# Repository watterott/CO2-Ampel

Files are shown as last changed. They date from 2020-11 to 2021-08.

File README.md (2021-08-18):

# CO2-Ampel
The CO2-Ampel is a traffic light to show the carbon dioxide concentration in a room.

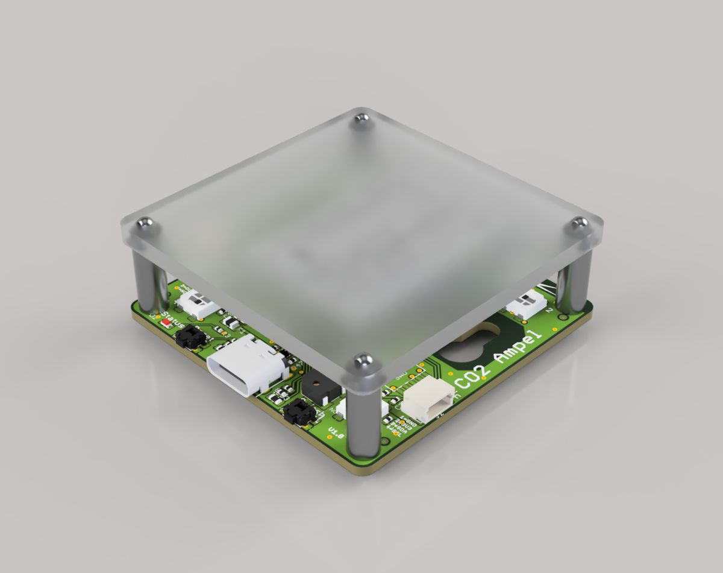
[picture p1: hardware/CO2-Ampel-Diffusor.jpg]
CO2-Ampel


* [Microchip ATSAMD21](https://www.microchip.com/wwwproducts/en/ATSAMD21G18) ARM Cortex-M0+ Microcontroller
* Sensirion [SCD30](https://www.sensirion.com/en/environmental-sensors/carbon-dioxide-sensors/carbon-dioxide-sensors-scd30/) or [SCD40/SCD41](https://www.sensirion.com/en/environmental-sensors/carbon-dioxide-sensors/carbon-dioxide-sensor-scd4x/) CO2 Sensor
* Intelligent WS2812 RGB-LEDs
* Acoustic Buzzer
* Plus Version:
  * [Microchip ATWINC1500B](http://www.microchip.com/wwwproducts/en/ATWINC1500) WiFi/WLAN Network Controller
* Pro Version:
  * Air Pressure Sensor
  * [Microchip ATWINC1500B](http://www.microchip.com/wwwproducts/en/ATWINC1500) WiFi/WLAN Network Controller (optional)
  * [HopeRF RFM95W/RFM96W](https://www.hoperf.com/modules/lora/index.html) LoRa Transceiver (optional)
* USB-C connector for power and data/programming
* USB CDC+MSC Bootloader (Arduino compatible)
* Open-Source and released under the [Creative Commons Attribution Share-Alike License](https://creativecommons.org/licenses/by-sa/4.0/).
* **[Documentation on learn.watterott.com](https://learn.watterott.com/breakouts/co2-ampel/)**

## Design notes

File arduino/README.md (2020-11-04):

# Board Support Package
Board Support Package for [Arduino IDE](https://www.arduino.cc/en/Main/Software).

## Installation

Add the following URL to the Arduino Boards Manager (*File->Preferences*):
```
https://github.com/watterott/CO2-Ampel/raw/master/package_co2ampel_index.json
```
Then open the Arduino Boards Manager (*Tools->Boards->Boards Manager*) and install the 
**Arduino SAMD Boards** and **CO2-Ampel Board**.

## Bootloader

The bootloader can be activated via the Arduino IDE or by doing two reset in 0.5s (double pressing the reset button next to the status LED).

When the bootloader is active then a new program can be loaded via the Arduino IDE and the serial port or via the mass storage device.
For the mass storage device just copy a new binary file (.bin) to the drive.

On Linux/Mac the dd command can be used to write the firmware: ```dd if=APP.BIN of=/media/CO2AMPEL/APP.BIN conv=notrunc```

A binary file can be generated and exported in the Arduino IDE with *Sketch->Export compiled Binary* command.

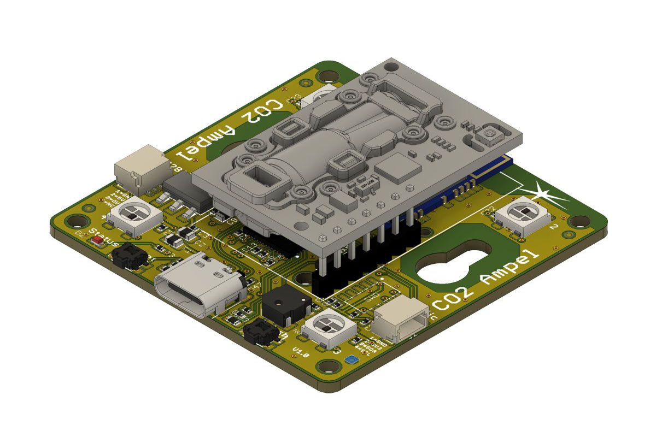
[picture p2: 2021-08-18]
hardware/CO2-Ampel_v10.jpg

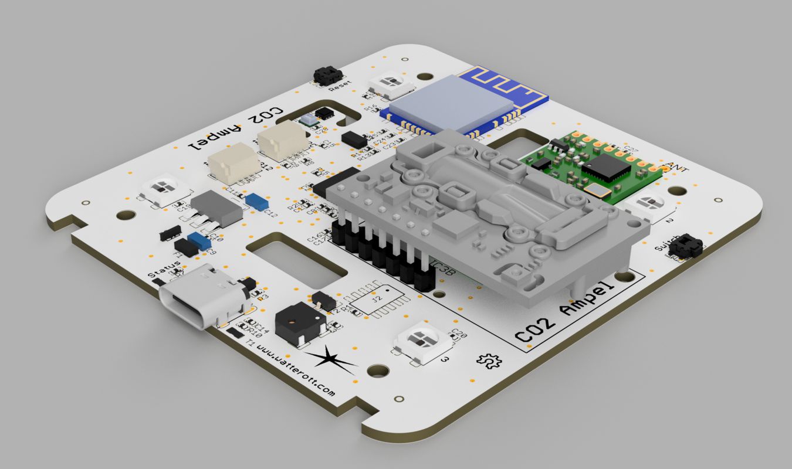
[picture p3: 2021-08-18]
hardware/CO2-Ampel-Pro_v12.jpg

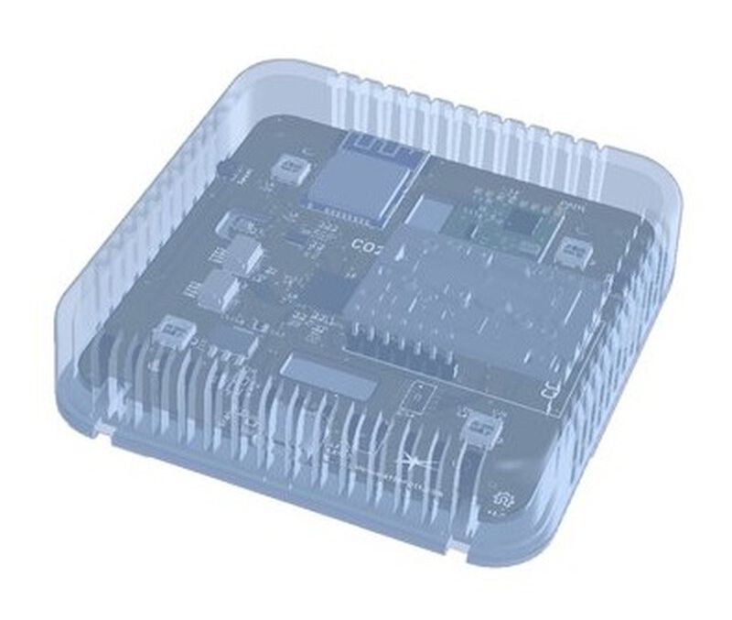
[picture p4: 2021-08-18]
hardware/CO2-Ampel-Pro-Enclosure.jpg

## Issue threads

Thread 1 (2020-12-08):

firmware v7 wrongly calibrated

ernstkl, 2020-12-08:
Hello,

the firmware v7 displays a CO2 ppm value of ca. 220 ppm in a well ventilated office. This is not plausible as fresh air has about 400 ppm CO2.
Doing the check outside, the ppm value drops to zero.

This looks like a wrong calibration to me. According to the readme, doing a calibration usually is not required.

ernstkl, 2020-12-08:
need to check, maybe we miscalibrated ourselves, sorry.

awatterott, 2020-12-08:
Please contact us via mail: support at watterott dot com

Closed 2020-12-08.

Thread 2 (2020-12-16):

Unpopulated component J2 next to Qwiic connector?

reibuehl, 2020-12-16:
I noticed that there is an unpopulated component, J2, next to the Qwiic connector J4 on the v1.1 board. Is there any information about what was supposed to be there?

awatterott, 2020-12-16:
Its a SWD connector for programming/debugging:
https://github.com/watterott/CO2-Ampel/blob/master/hardware/CO2-Ampel_v11.pdf
Please use our support mail address for technical questions.

Closed 2020-12-16.

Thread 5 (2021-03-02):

Firmware co2_covid_v11.bin doesn't seem to work well with v1.1 standard device

olberger, 2021-03-02:
I have tested the co2_covid_v11.bin firmware from
https://learn.watterott.com/breakouts/co2-ampel/getting-started/co2_covid_v11.bin and values reported over the USB serial port (and light colors) seem to be varying to erratically, on my v1.1 standard version.

Firmware co2_covid_v10.bin seems more reliable (smoother evolution of CO2 level).

Maybe this is known : "could cause freezing of standard version on startup (since v5)" seems to indicate a problem with the standard version... or I misunderstand the meaning of that notice : not clear if it applies to the prior versions (bug fixed), or is a known issue with that update... proper changelog/release notes would help (maybe not in the getting started page, but couldn't find more docs...)

Thanks in advance.

awatterott, 2021-03-02:
The different between v10 and v11 is just a fix for the possible freezing, which was caused by the detection code for the plus version.

olberger, 2021-03-02:
OK, so what about the fact that v11 doesn't report values in a sensible way ?

It's no big deal, but may I complain a bit about the quickly closed issues I've just experienced. Please, don't close issues when you responded only to the last sentence, and when the initial part of my issue (and the summary) is the real problem...

It looks like you're worried about issues open... and seems a bit rude for the reporter (who's also a customer FWIW)... I'm just trying to help, and not blaming specifically, but I tend to feel like the issues aren't address somehow.

Or just that's not the place for such discussion... sorry then, but there doesn't seem to be any proper docs about how to report issues anywhere... so... again I don't want to be rude either to you, but it's just a bit confusing without more details on the expected procedures...

Thanks in advance / Vielen Dank.

awatterott, 2021-03-02:
The CO2 values over USB are directly from the SCD30 sensor and the LEDs show an average of those values, which will lead the LEDs to a slower reaction.
Note, with enabled remote mode the measurement interval will be 2s and the default is 3s.
But this is not an issue and if you have technical questions then please contact us via mail.

Closed 2021-03-02.

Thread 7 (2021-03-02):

No values detected on serial link until I flashed the v10+ firmware

olberger, 2021-03-02:
Is there a known issue (undocumented ?) on standard device which could become silent over serial ?

I seem to had proper serial config with cutecom and /dev/ttyACM0 (9600, 8-N1 etc.) but couldn't detect anything on the serial line. Leds were working fine (supposedly, changing to green when getting fresh air, etc.)

After I flashed the v11 firmware, it suddenly started to report sensor values.

Also I couldn't figure out how to detect which version of firmware was running initially as shipped from the store... but that's probably another issue ;-)

awatterott, 2021-03-02:
With v10 the USB detection was changed and previously flow control was used via Arduino Serial functions, which only works directly with the Arduino IDE.
https://github.com/watterott/CO2-Ampel/blob/master/arduino/samd/libraries/CO2-Ampel/examples/CO2-Ampel/CO2-Ampel.ino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
There is currently no command to receive the version of the firmware.

olberger, 2021-03-02:
Uh, sorry but I fail to understand if the above response is supposed to explain why I couldn't see any traffic on the USB serial... Could you explain for someone without knowledge of Arduino stuff ?

awatterott, 2021-03-02:
If the firmware/CO2-Ampel does not detect a USB host device, then no data will be sent via the USB serial port.

Closed 2021-03-02.

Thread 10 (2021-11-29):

checksum in package json missing

sbernhard, 2021-11-29:
**Describe the bug**
The installation of the following command fails because of checksum error.

```arduino-cli core install co2ampel:samd```

Error:
```
Error during install: Cannot install platform: installing platform co2ampel:samd@1.0.7: testing local archive integrity: testing archive checksum: missing checksum for: co2ampel-samd-1.0.7.zip
```

**Expected behavior**
The installation of the co2ampel:samd is successful

**Additional context**
The file https://github.com/watterott/CO2-Ampel/blob/master/package_co2ampel_index.json is missing the checksum like in https://boardsmanager.com/package_move38.com-blinks_index.json

Closed 2022-04-22.

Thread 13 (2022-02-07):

Wifi connection crashes after 1 1/2 day running

HaeckslerSXS, 2022-02-07:
We bought this sensor to messure CO2 in our office, unfortunately the Wifi connection crashes frequently.
We think it would help I we would have the possibility to enter a fix IP.

awatterott, 2022-02-07:
Can you please contact us by email to troubleshoot the problem/issue at first:
https://shop.watterott.com/Contact
We have seen a similar behavior with Ubiquiti devices with an old firmware.

Closed 2022-04-22.

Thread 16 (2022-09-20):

WPA2 Enterprise

realjago, 2022-09-20:
[Feature Request]

hallo, wir verwenden einige CO2-Ampeln und funktioniert sehr gut.
Wir möchten diese auch im Hochschulkontext einsetzen. Lufthygiene in Hörsälen zB.
Dort gibt es aber kein klassisches WPA2, sondern nur WPA2 Enterprise (eduroam), also mit zusätzlichem Benutzer und Passwort zur Verbindung mit dem WLAN.

Es wäre fantastisch, wenn diese Funktionalität noch eingebaut werden könnte.
Das würde auch dafür sorgen, dass noch mehr dieser Geräte bei Ihnen eingekauft werden.

awatterott, 2022-09-21:
Dies ist prinzipiell möglich. Allerdings fehlt in der Arduino WiFi101 Bibliothek aktuell die Unterstützung dafür und eine Umsetzung wäre dadurch sehr aufwendig.
https://github.com/arduino-libraries/WiFi101/issues/199

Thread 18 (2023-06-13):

Hysterese?

mschlenker, 2023-06-13:
In unserem Unternehmen nutzen wir einige CO2-Ampeln für die Überwachung der Luftqualität (wofür sonst...). Leider haben wir festgestellt, dass das Lüftungsverhalten gerade so ist, dass die Schotten wieder dicht gemacht werden, wenn die Ampel gerade so wieder grün ist (oder die Email mit "WARN -> OK" kommt). Für das Checkmk-Plugin bin ich daher dabei, einen Hysteresefaktor als festen Prozentsatz einstellbar zu machen.

D.h., wenn der Übergang OK -> WARN bei Überschreiten von 1000ppm stattfindet und ein Hysteresefaktor von 10% eingestellt ist, findet der Übergang von WARN -> OK erst statt, wenn 900ppm unterschritten werden.

Wenn Ihr daran interessiert seid, den Code für die Hysterese zu übernehmen, werde ich den Code entsprechend sauber strukturieren und gut kommentieren und dann als Pull-Request einreichen. Wäre das in Eurem Interesse?

Liebe Grüße
Mattias

awatterott, 2023-06-13:
Zur Orientierung für das Ende einer Lüftung dient der blaue Bereich (<600ppm).

mschlenker, 2023-06-13:
Hallo Andreas,

Das ist der Idealfall und letztendlich eine Interpretation einer extremen Hysterese. In vielen Umgebungen bedeutet das sehr lange Lüftungszeiten. ASR 3.6 ist zwischen 1000ppm und 2000ppm auch recht flexibel. Ich teste unsere Hysterese nächste Woche mal auf der Checkmk Konferenz und gebe dann nochmal Feedback.

Schönen Abend!
Mattias

Closed 2023-06-24.

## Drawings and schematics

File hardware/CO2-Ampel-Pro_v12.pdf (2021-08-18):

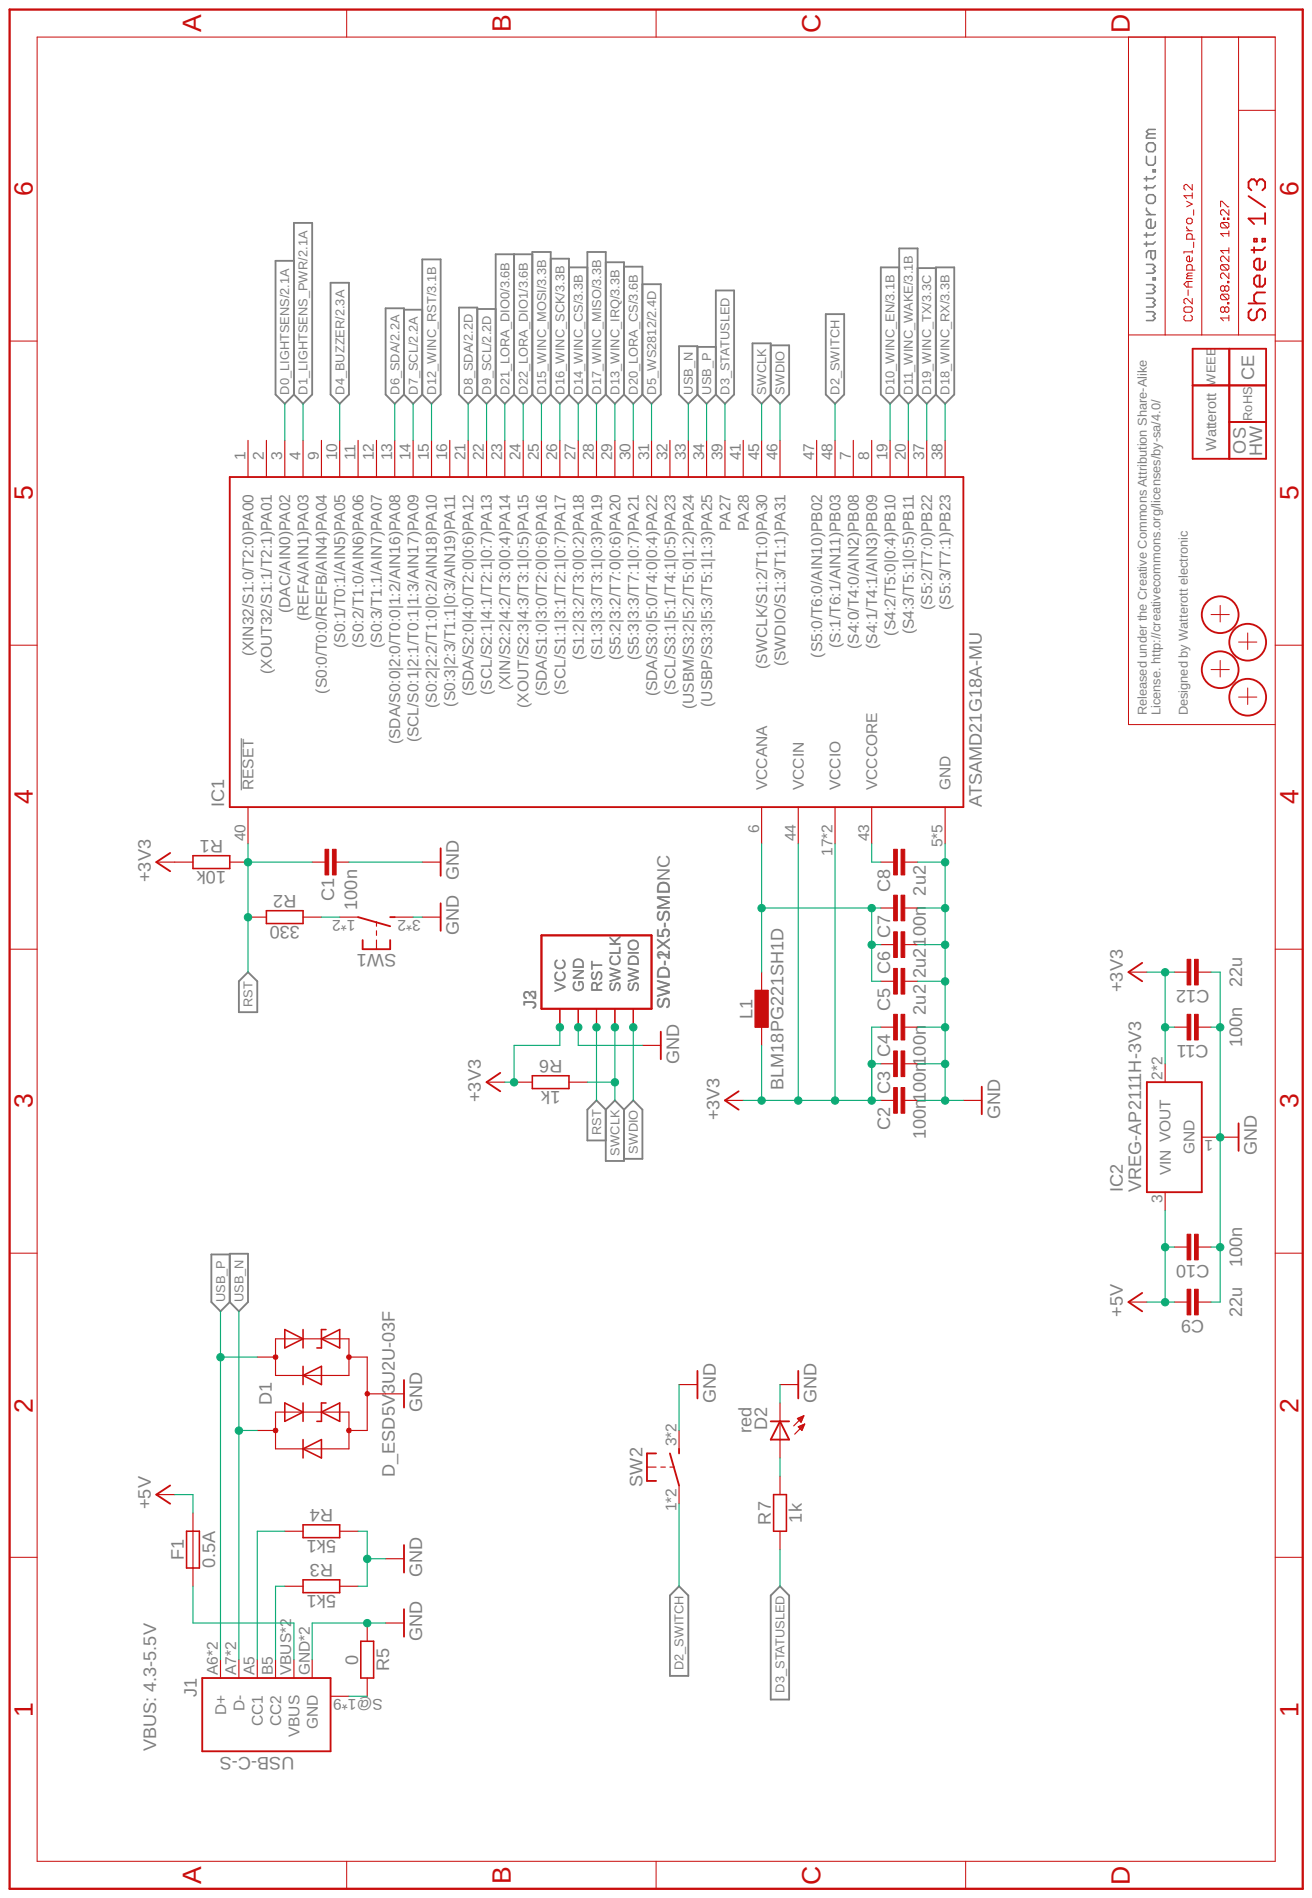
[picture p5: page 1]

VBUS: 4.3-5.5V ATSAMD21G18A-MU +3V3 GND +3V3 GND 0 0.5A +5VD_ESD5V3U2U-03F GND VREG-AP2111H-3V3 +5V GND 100n 100n red 1k 2u2 100n 2u2 100n GND GND k01 033 +3V3 k1 100n 100n 100n 22u 22u GND +3V3 GND BLM18PG221SH1D 2u2 GND 1k5 1k5 GND Released under the Creative Commons Attribution Share-Alike License. http:/ creativecommons.org/licenses/by-sa/4.0/ Designed by Watterott electronic OS HW RESET 40 GND 5*5 VCCANA 6 (XIN32/S1:0/T2:0)PA00 1 (XOUT32/S1:1/T2:1)PA01 2 (DAC/AIN0)PA02 3 (REFA/AIN1)PA03 4 (S0:0/T0:0/REFB/AIN4)PA04 9 (S0:1/T0:1/AIN5)PA05 10 (S0:2/T1:0/AIN6)PA06 11 (S0:3/T1:1/AIN7)PA07 12 (SDA/S0:0|2:0/T0:0|1:2/AIN16)PA08 13 (SCL/S0:1|2:1/T0:1|1:3/AIN17)PA09 14 (S0:2|2:2/T1:0|0:2/AIN18)PA10 15 (S0:3|2:3/T1:1|0:3/AIN19)PA11 16 (SDA/S2:0|4:0/T2:0|0:6)PA12 21 (SCL/S2:1|4:1/T2:1|0:7)PA13 22 (XIN/S2:2|4:2/T3:0|0:4)PA14 23 (XOUT/S2:3|4:3/T3:1|0:5)PA15 24 (SDA/S1:0|3:0/T2:0|0:6)PA16 25 (SCL/S1:1|3:1/T2:1|0:7)PA17 26 (S1:2|3:2/T3:0|0:2)PA18 27 (S1:3|3:3/T3:1|0:3)PA19 28 (S5:2|3:2/T7:0|0:6)PA20 29 (S5:3|3:3/T7:1|0:7)PA21 30 (SDA/S3:0|5:0/T4:0|0:4)PA22 31 (SCL/S3:1|5:1/T4:1|0:5)PA23 32 (USBM/S3:2|5:2/T5:0|1:2)PA24 33 (USBP/S3:3|5:3/T5:1|1:3)PA25 34 PA27 39 PA28 41 (SWCLK/S1:2/T1:0)PA30 45 (SWDIO/S1:3/T1:1)PA31 46 (S5:0/T6:0/AIN10)PB02 47 (S:1/T6:1/AIN11)PB03 48 (S4:0/T4:0/AIN2)PB08 7 (S4:1/T4:1/AIN3)PB09 8 (S4:2/T5:0|0:4)PB10 19 (S4:3/T5:1|0:5)PB11 20 (S5:2/T7:0)PB22 37 (S5:3/T7:1)PB23 38 VCCIO 17*2 VCCIN 44 VCCCORE 43 IC1 2* 1 2* 3 1 WS SWCLK SWDIO VCC GND RST J2SWD-2X5-SMD R5 F1 D1 GND VIN 3 V1 OUT 2*2 IC2 01 C 11 C D2 R7 C8 C7 C5 C1 1 R 2 R 6 R C4 C3 C2 9 C 21 C 1*2 3*2 SW2 L1 C6 CE RoHSWEEE Watterott D+ A6*2 D- A7*2 VBUS VBUS*2 GND GND*2 9* 1 @S CC1 A5 CC2 B5 J1 S- C- BSU 3 R4 R SWCLK SWDIO VCC GND RST J3SWD-1X5-SMDNC D15_WINC_MOSI/3.3B D16_WINC_SCK/3.3B D6_SDA/2.2A D7_SCL/2.2A SWCLK SWCLK SWDIO SWDIO RST RST D17_WINC_MISO/3.3B USB_N USB_N USB_P USB_P D11_WINC_WAKE/3.1B D14_WINC_CS/3.3B D18_WINC_RX/3.3B D19_WINC_TX/3.3C D13_WINC_IRQ/3.3B D8_SDA/2.2D D9_SCL/2.2D D5_WS2812/2.4D D10_WINC_EN/3.1B D4_BUZZER/2.3A D2_SWITCH D2_SWITCH D12_WINC_RST/3.1B D1_LIGHTSENS_PWR/2.1A D0_LIGHTSENS/2.1A D3_STATUSLED D3_STATUSLED D22_LORA_DIO1/3.6B D21_LORA_DIO0/3.6B D20_LORA_CS/3.6B ABCD 1 2 3 4 5 6 ABCD 1 2 3 4 5 6

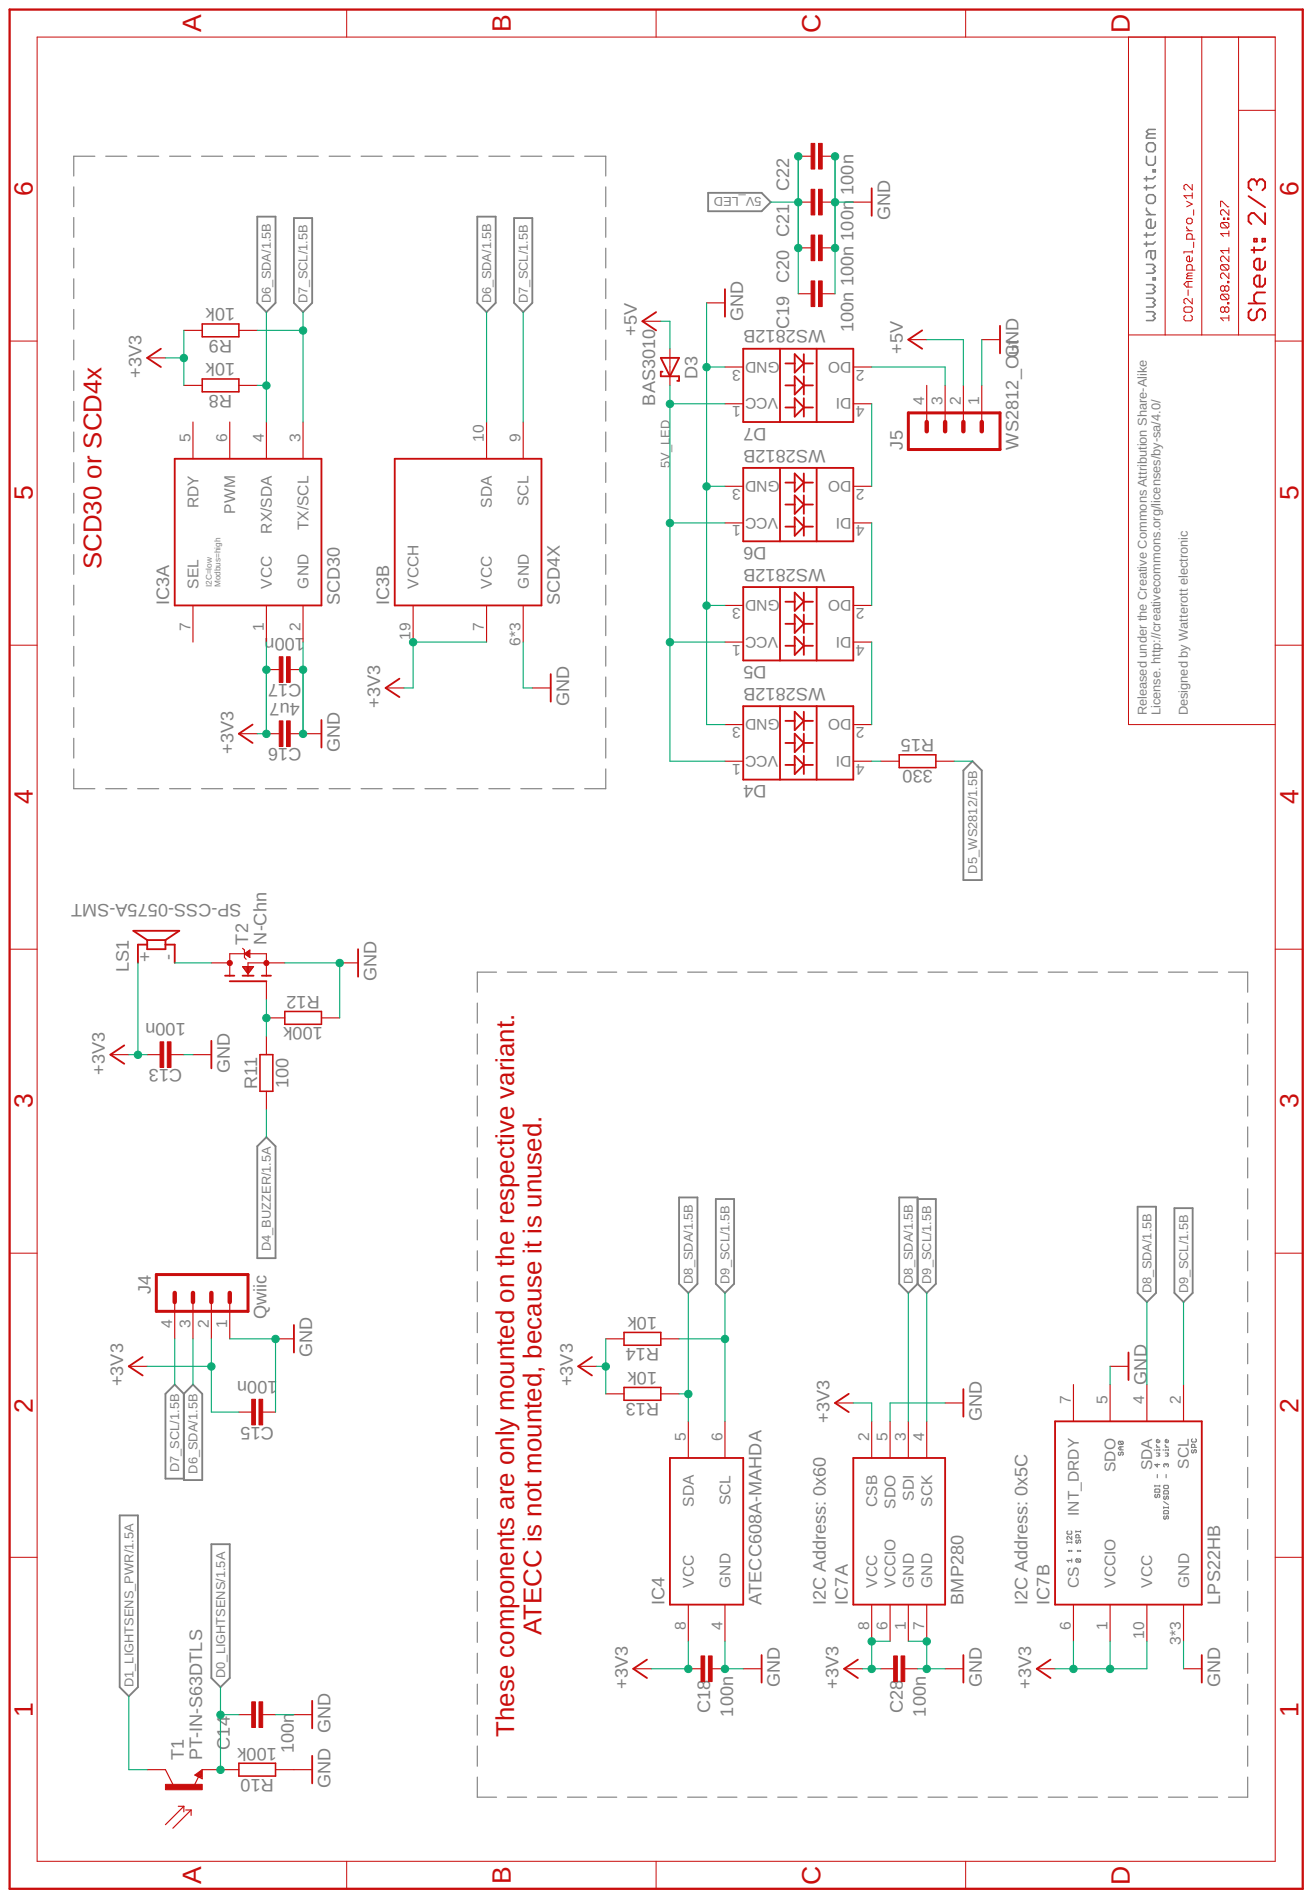
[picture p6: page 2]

I2C Address: 0x60 I2C Address: 0x5C B2182S W B2182S W B2182S W B2182S W SCD30 GND 033 +3V3 GND 100n 100n 100n GND k001 GND Qwiic GND +3V3 N-Chn +3V3 GND k001 100 +3V3 100nGND WS2812_Out GND +5V 100nGND n001 7u4 100n n001 n001 GND k01 k01 +3V3 k01 k01 +3V3 BAS301 +0 5V T MS- A5750- SSC- PS PT-IN-S63DTLS BMP280 100+n3V3 GND +3V3 GND SCD4X +3V3 GND LPS22HB GND +3V3 GND Released under the Creative Commons Attribution Share-Alike License. http:/ creativecommons.org/licenses/by-sa/4.0/ Designed by Watterott electronic 42 13 CCV DNG ODI D 7 D 42 13 CCV DNG ODI D 6 D 42 13 CCV DNG ODI D 5 D 42 13 CCV DNG ODI D 4 D TX/SCL 3 VCC 1 RX/SDA 4 GND 2 PWM 6 RDY 5 SEL 7 I2C=low Modbus=high IC3A 51 R C20 C21 C22 01 R 4321 J4 T2 21 R R11 C18 SCL 6 SDA 5 VCC 8 GND 4 IC4 ATECC608A-MAHDA 4321 J5 C14 71 C 61 C C19 51 C 31 C 31 R 41 R 8 R9 R D3 +- LS1 T1 GND 1 CSB 2 SDI 3 SCK 4 SDO 5 VCCIO 6 GND 7 VCC 8 IC7A C28 SCL 9 VCC 7 SDA 10 GND 6*3 VCCH 19 IC3B SCL 2 VCC 10 SDA 4 GND 3*3 CS 6 SDO 5 INT_DRDY 7 VCCIO 1 IC7B D5_WS2812/1.5B D6_SDA/1.5B D6_SDA/1.5B D6_SDA/1.5B D7_SCL/1.5B D7_SCL/1.5B D7_SCL/1.5B D0_LIGHTSENS/1.5A D4_BUZZER/1.5A D8_SDA/1.5B D8_SDA/1.5B D8_SDA/1.5B D9_SCL/1.5B D9_SCL/1.5B D9_SCL/1.5B D1_LIGHTSENS_PWR/1.5A 5V_LED DEL_V5 These components are only mounted on the respective variant. ATECC is not mounted, because it is unused. SCD30 or SCD4x ABCD 1 2 3 4 5 6 ABCD 1 2 3 4 5 6

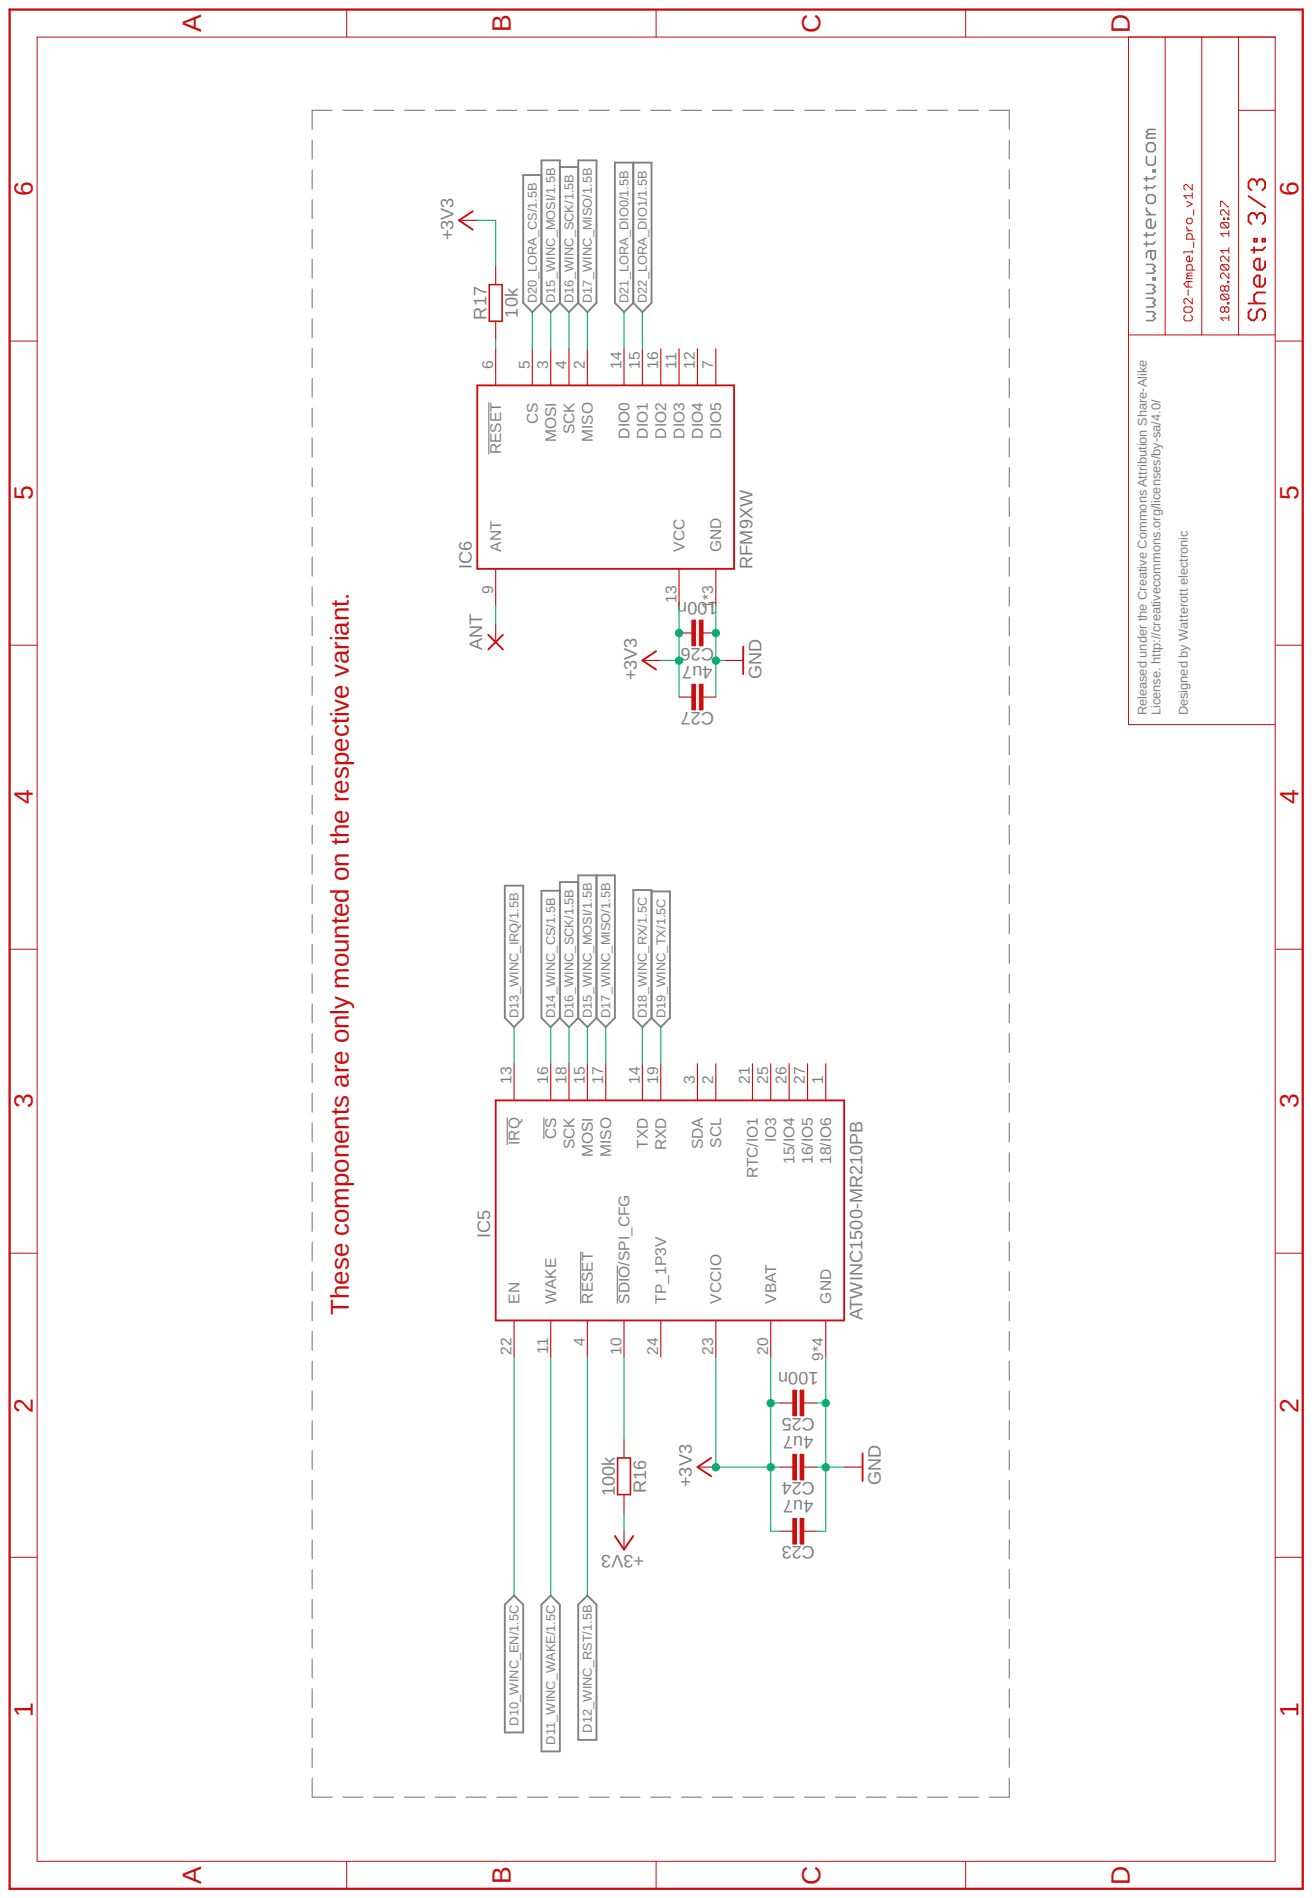
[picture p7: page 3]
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

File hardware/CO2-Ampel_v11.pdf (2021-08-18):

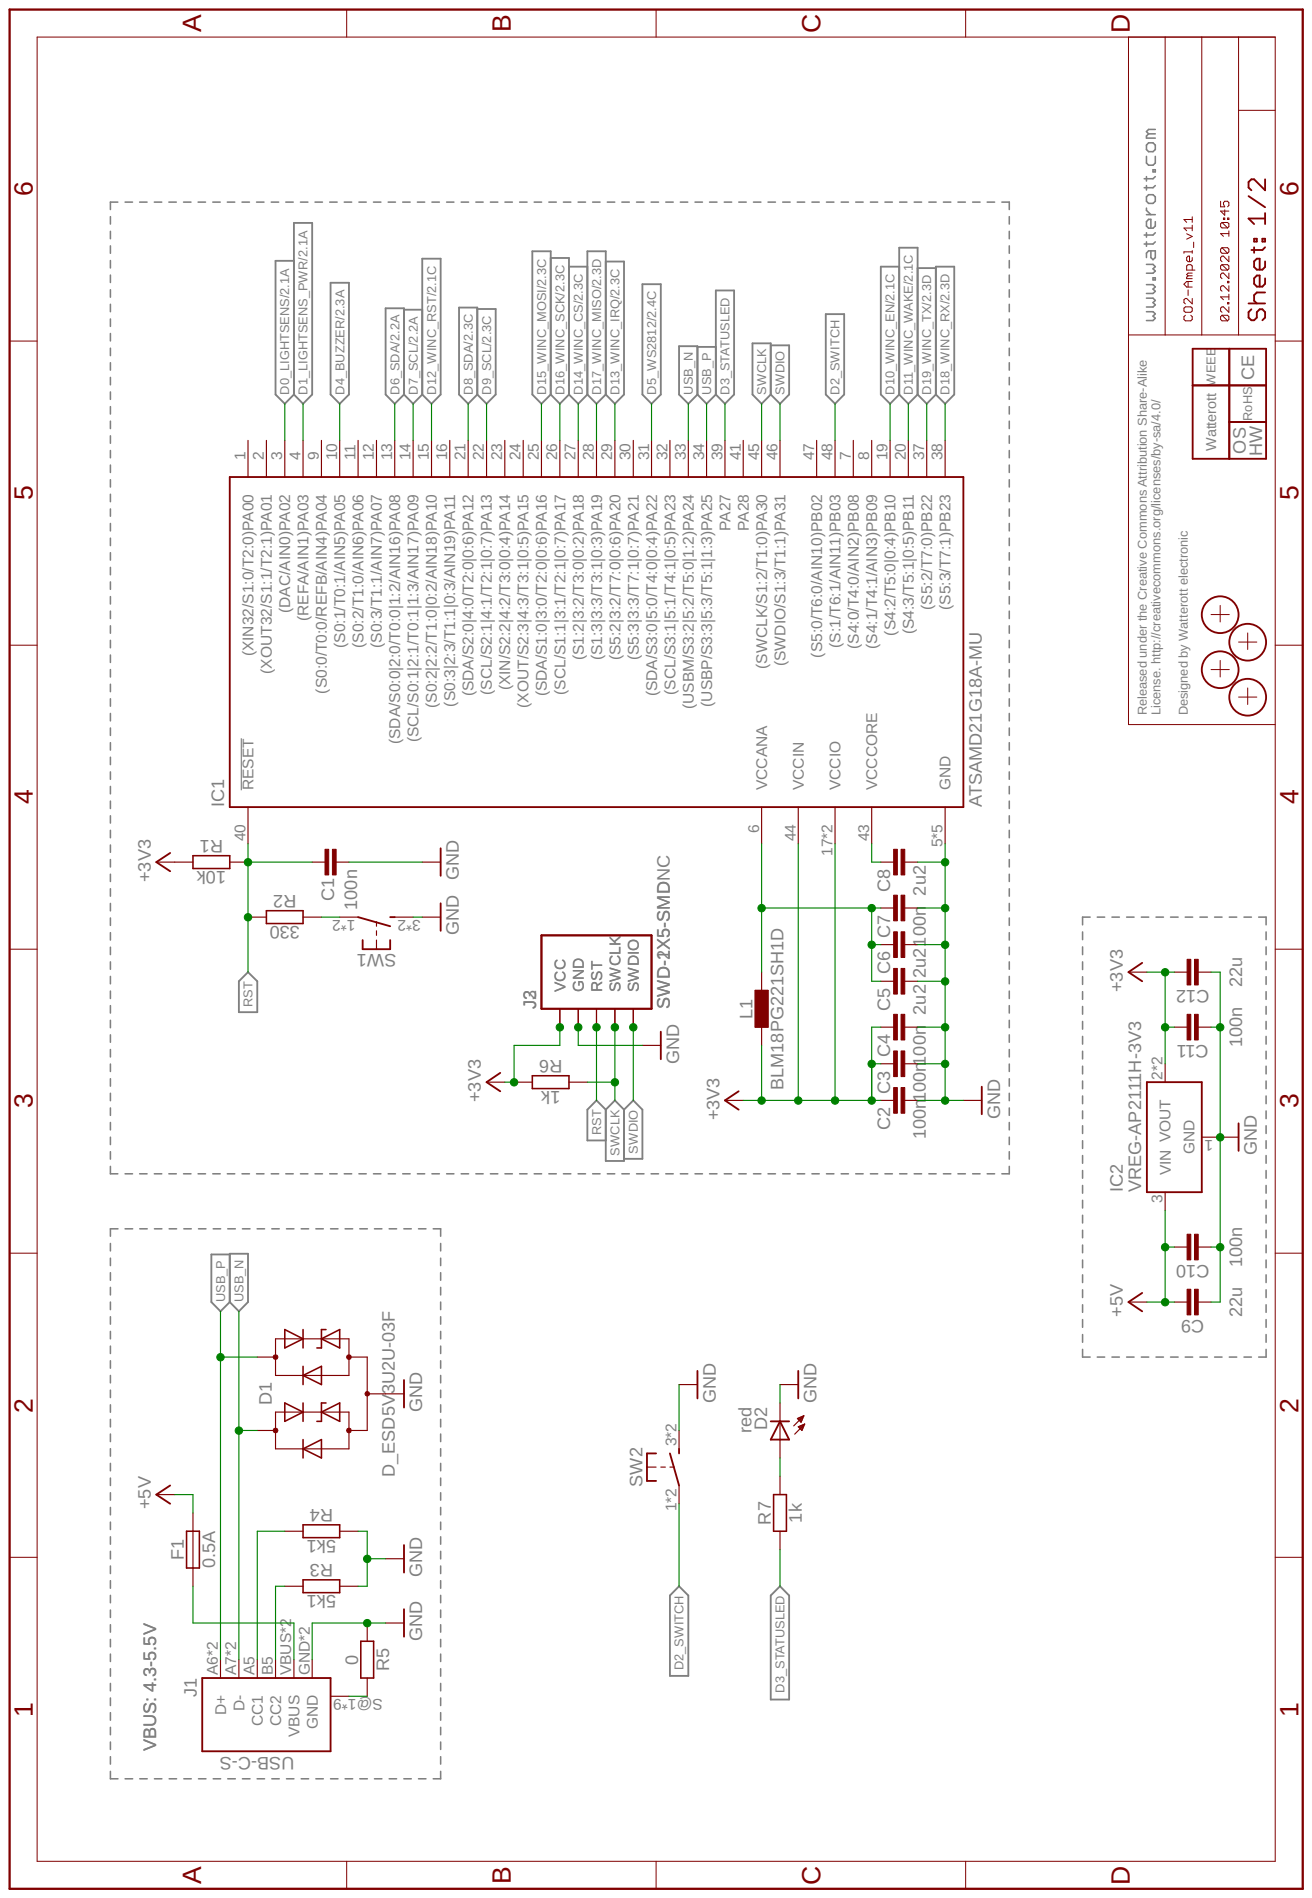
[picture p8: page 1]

VBUS: 4.3-5.5V VBUS: 4.3-5.5V ATSAMD21G18A-MU +3V3 GND +3V3 GND 0 0.5A +5VD_ESD5V3U2U-03F GND VREG-AP2111H-3V3 +5V GND 100n 100n red 1k 2u2 100n 2u2 100n GND GND k01 033 +3V3 k1 100n 100n 100n 22u 22u GND +3V3 GND BLM18PG221SH1D 2u2 GND 1k5 1k5 GND Released under the Creative Commons Attribution Share-Alike License. http:/ creativecommons.org/licenses/by-sa/4.0/ Designed by Watterott electronic OS HW RESET 40 GND 5*5 VCCANA 6 (XIN32/S1:0/T2:0)PA00 1 (XOUT32/S1:1/T2:1)PA01 2 (DAC/AIN0)PA02 3 (REFA/AIN1)PA03 4 (S0:0/T0:0/REFB/AIN4)PA04 9 (S0:1/T0:1/AIN5)PA05 10 (S0:2/T1:0/AIN6)PA06 11 (S0:3/T1:1/AIN7)PA07 12 (SDA/S0:0|2:0/T0:0|1:2/AIN16)PA08 13 (SCL/S0:1|2:1/T0:1|1:3/AIN17)PA09 14 (S0:2|2:2/T1:0|0:2/AIN18)PA10 15 (S0:3|2:3/T1:1|0:3/AIN19)PA11 16 (SDA/S2:0|4:0/T2:0|0:6)PA12 21 (SCL/S2:1|4:1/T2:1|0:7)PA13 22 (XIN/S2:2|4:2/T3:0|0:4)PA14 23 (XOUT/S2:3|4:3/T3:1|0:5)PA15 24 (SDA/S1:0|3:0/T2:0|0:6)PA16 25 (SCL/S1:1|3:1/T2:1|0:7)PA17 26 (S1:2|3:2/T3:0|0:2)PA18 27 (S1:3|3:3/T3:1|0:3)PA19 28 (S5:2|3:2/T7:0|0:6)PA20 29 (S5:3|3:3/T7:1|0:7)PA21 30 (SDA/S3:0|5:0/T4:0|0:4)PA22 31 (SCL/S3:1|5:1/T4:1|0:5)PA23 32 (USBM/S3:2|5:2/T5:0|1:2)PA24 33 (USBP/S3:3|5:3/T5:1|1:3)PA25 34 PA27 39 PA28 41 (SWCLK/S1:2/T1:0)PA30 45 (SWDIO/S1:3/T1:1)PA31 46 (S5:0/T6:0/AIN10)PB02 47 (S:1/T6:1/AIN11)PB03 48 (S4:0/T4:0/AIN2)PB08 7 (S4:1/T4:1/AIN3)PB09 8 (S4:2/T5:0|0:4)PB10 19 (S4:3/T5:1|0:5)PB11 20 (S5:2/T7:0)PB22 37 (S5:3/T7:1)PB23 38 VCCIO 17*2 VCCIN 44 VCCCORE 43 IC1 2* 1 2* 3 1 WS SWCLK SWDIO VCC GND RST J2SWD-2X5-SMD R5 F1 D1 GND VIN 3 V1 OUT 2*2 IC2 01 C 11 C D2 R7 C8 C7 C5 C1 1 R 2 R 6 R C4 C3 C2 9 C 21 C 1*2 3*2 SW2 L1 C6 CE RoHSWEEE Watterott D+ A6*2 D- A7*2 VBUS VBUS*2 GND GND*2 9* 1 @S CC1 A5 CC2 B5 J1 S- C- BSU 3 R4 R SWCLK SWDIO VCC GND RST J3SWD-1X5-SMDNC D15_WINC_MOSI/2.3C D16_WINC_SCK/2.3C D6_SDA/2.2A D7_SCL/2.2A SWCLK SWCLK SWDIO SWDIO RST RST D17_WINC_MISO/2.3D USB_N USB_N USB_P USB_P D11_WINC_WAKE/2.1C D14_WINC_CS/2.3C D18_WINC_RX/2.3D D19_WINC_TX/2.3D D13_WINC_IRQ/2.3C D8_SDA/2.3C D9_SCL/2.3C D5_WS2812/2.4C D10_WINC_EN/2.1C D4_BUZZER/2.3A D2_SWITCH D2_SWITCH D12_WINC_RST/2.1C D1_LIGHTSENS_PWR/2.1A D0_LIGHTSENS/2.1A D3_STATUSLED D3_STATUSLED ABCD 1 2 3 4 5 6 ABCD 1 2 3 4 5 6

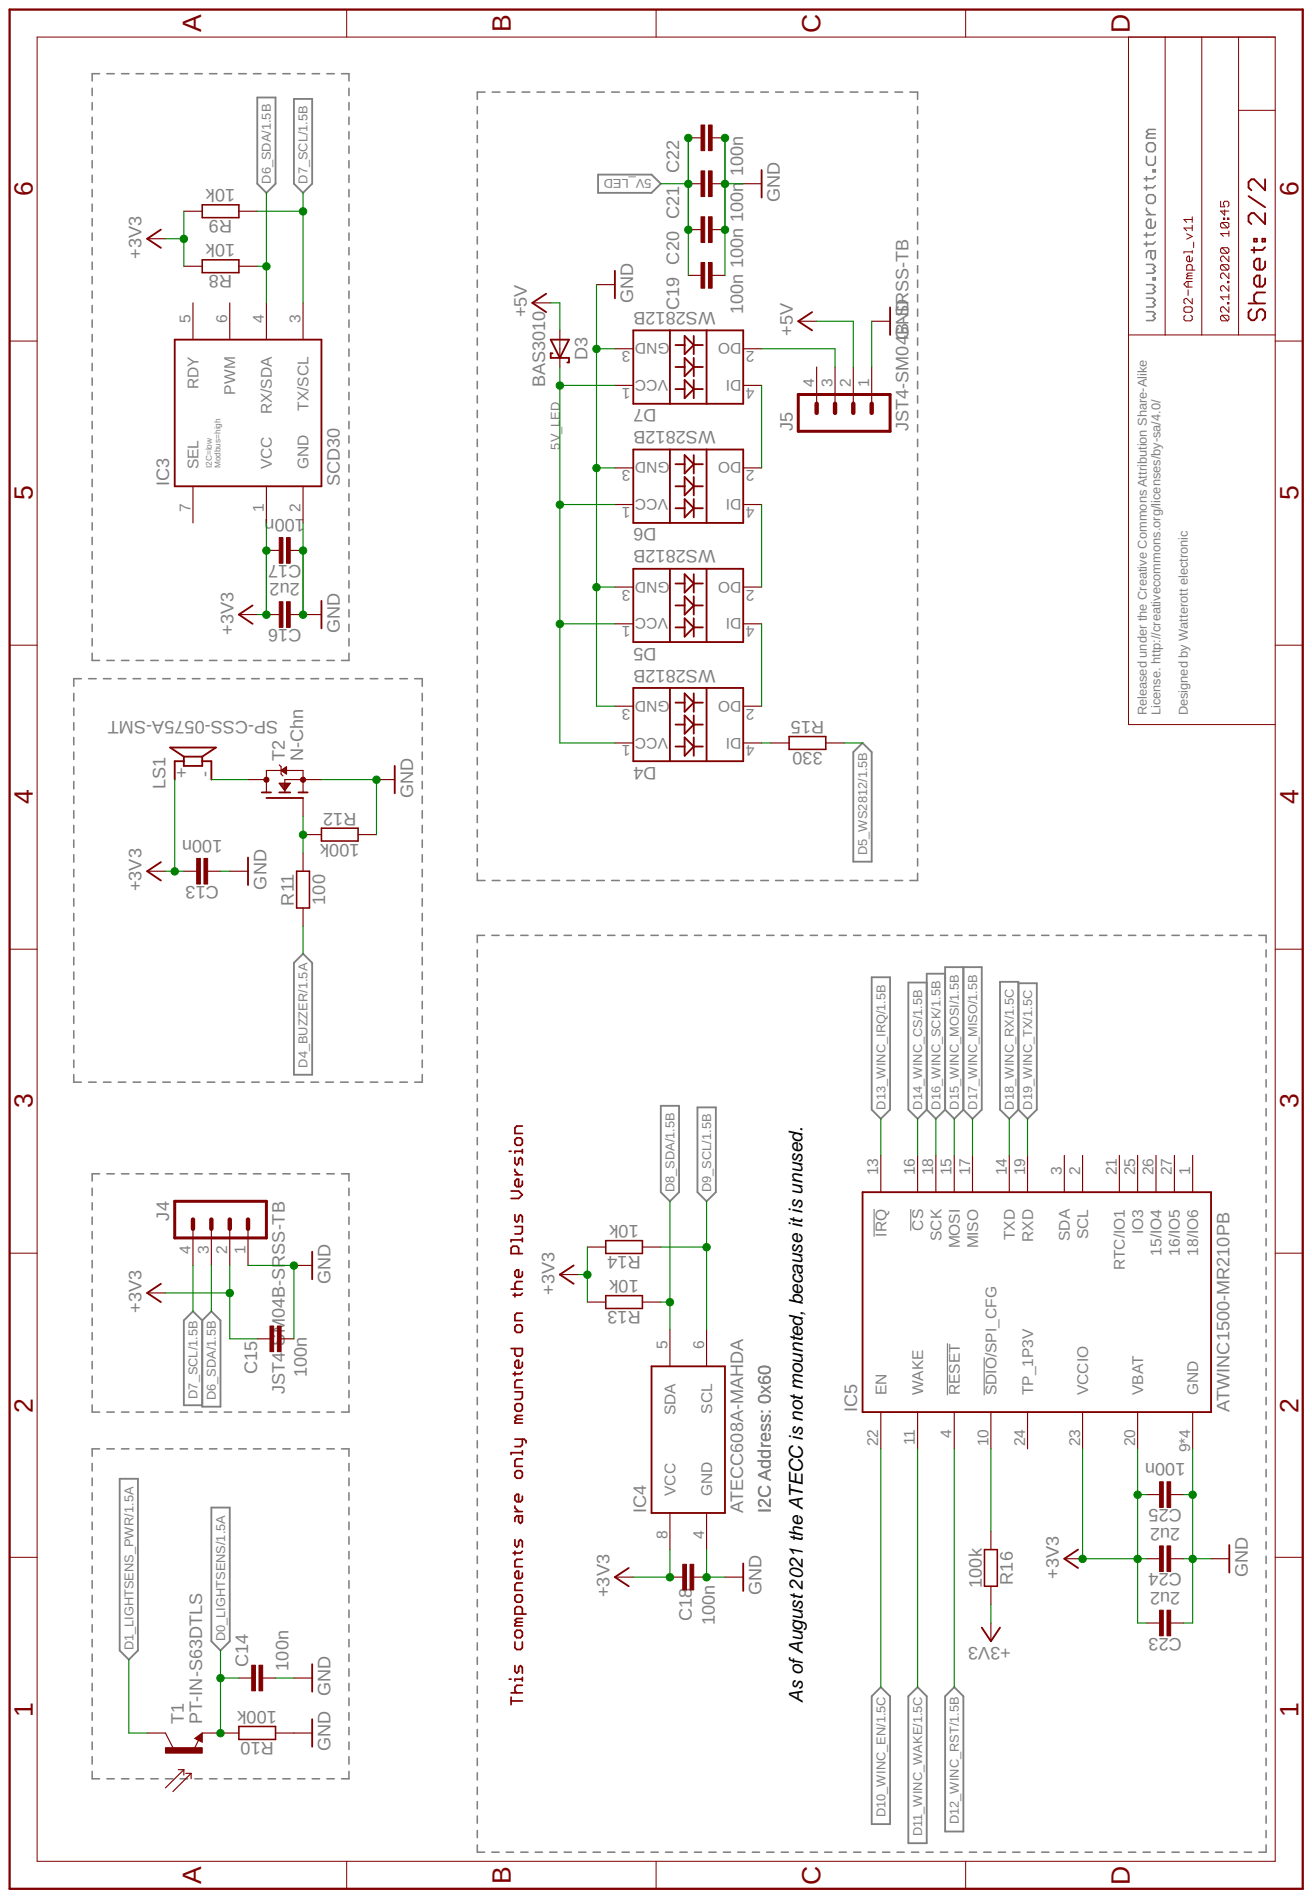
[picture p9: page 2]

I2C Address: 0x60 I2C Address: 0x60 n001 +3V3 GND 3V3+ 100k ATWINC1500-MR210PB 2u2 B2182S W B2182S W B2182S W B2182S W SCD30 GND 033 +3V3 GND 100n 100n 100n GND k001 GND JST4-SM04B-SRSS-TB GND +3V3 N-Chn +3V3 GND k001 100 +3V3 100nGND JST4-SM04B-SRSS-TB GND +5V 100n GND 2u2 n001 2u2 100n 100n n001 GND k01 k01 +3V3 k01 k01 +3V3 BAS301 +0 5V T MS- A5750- SSC- PS PT-IN-S63DTLS Released under the Creative Commons Attribution Share-Alike License. http:/ creativecommons.org/licenses/by-sa/4.0/ Designed by Watterott electronic 52 C R16 16/IO5 27 SCL 2 SDA 3 RESET 4 GND 9*4 SDIO/SPI_CFG 10 WAKE 11 IRQ 13 TXD 14 MOSI 15 CS 16 MISO 17 SCK 18 RXD 19 VBAT 20 RTC/IO1 21 EN 22 VCCIO 23 18/IO6 1 IO3 25 15/IO4 26 TP_1P3V 24 IC5 42 C 42 13 CCV DNG ODI D 7 D 42 13 CCV DNG ODI D 6 D 42 13 CCV DNG ODI D 5 D 42 13 CCV DNG ODI D 4 D TX/SCL 3 VCC 1 RX/SDA 4 GND 2 PWM 6 RDY 5 SEL 7 I2C=low Modbus=high IC3 51 R C20 C21 C22 01 R 4321 J4 T2 21 R R11 C18 SCL 6 SDA 5 VCC 8 GND 4 IC4 ATECC608A-MAHDA 4321 J5 C1432 C 71 C 61 C C19 C15 31 C 31 R 41 R 8 R9 R D3 +- LS1 T1 D15_WINC_MOSI/1.5B D16_WINC_SCK/1.5B D17_WINC_MISO/1.5B D18_WINC_RX/1.5C D10_WINC_EN/1.5C D11_WINC_WAKE/1.5C D5_WS2812/1.5B D12_WINC_RST/1.5B D6_SDA/1.5B D6_SDA/1.5B D7_SCL/1.5B D7_SCL/1.5B D0_LIGHTSENS/1.5A D4_BUZZER/1.5A D8_SDA/1.5B D9_SCL/1.5B D14_WINC_CS/1.5B D19_WINC_TX/1.5C D1_LIGHTSENS_PWR/1.5A D13_WINC_IRQ/1.5B 5V_LED DEL_V5 ABCD 1 2 3 4 5 6 ABCD 1 2 3 4 5 6 As of August 2021 the ATECC is not mounted, because it is unused.

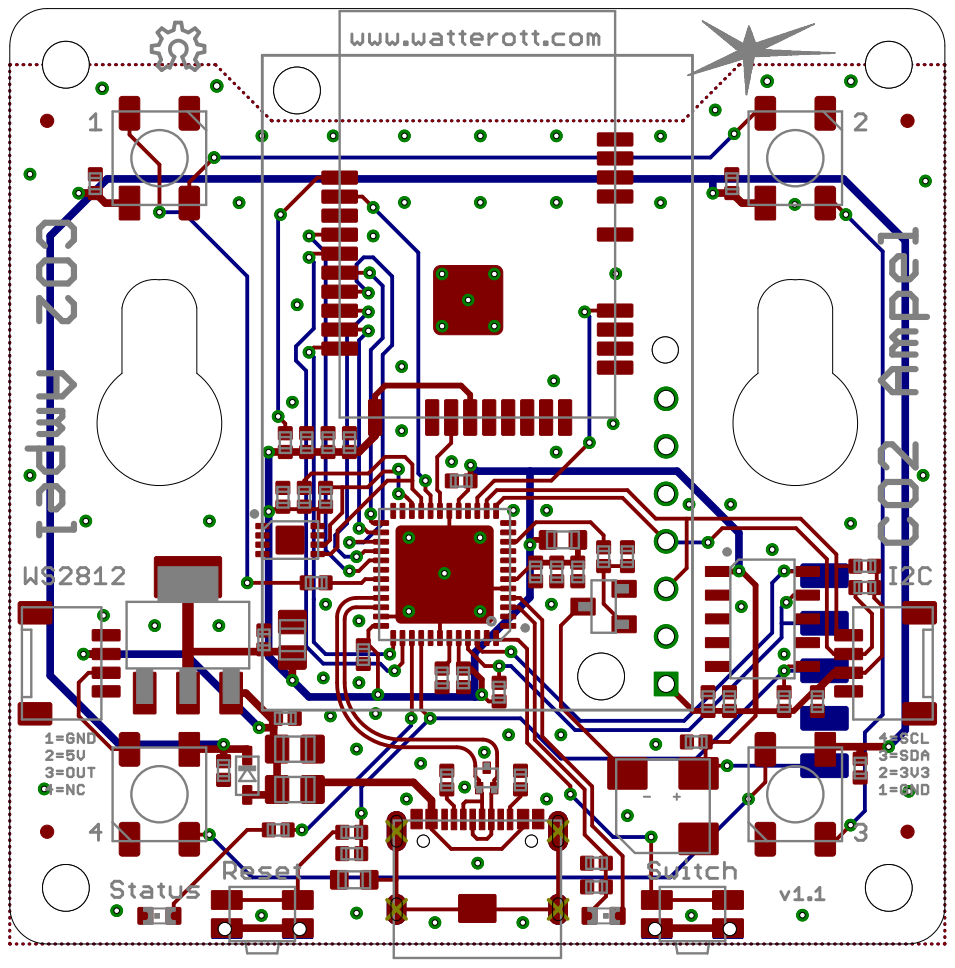
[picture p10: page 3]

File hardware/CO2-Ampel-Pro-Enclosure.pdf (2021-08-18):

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

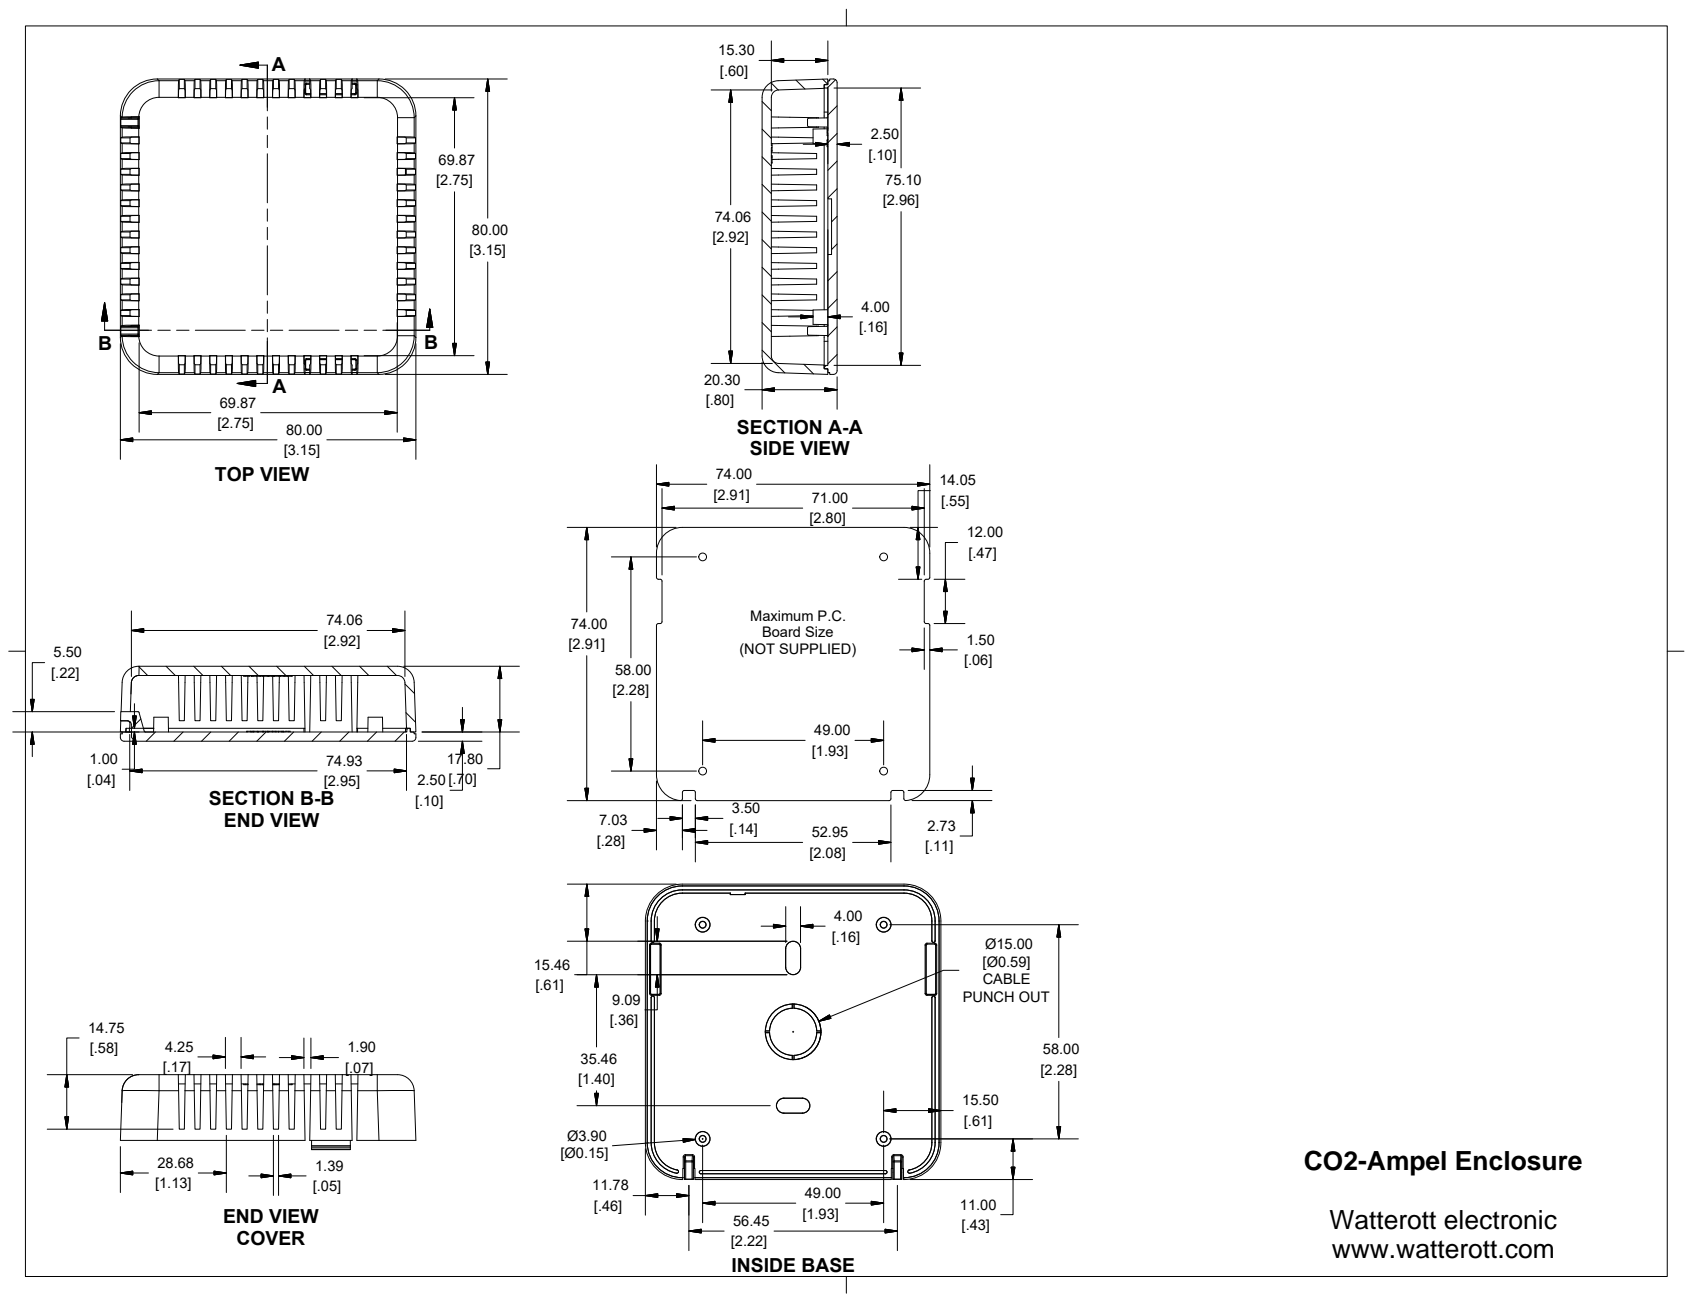
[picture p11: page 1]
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

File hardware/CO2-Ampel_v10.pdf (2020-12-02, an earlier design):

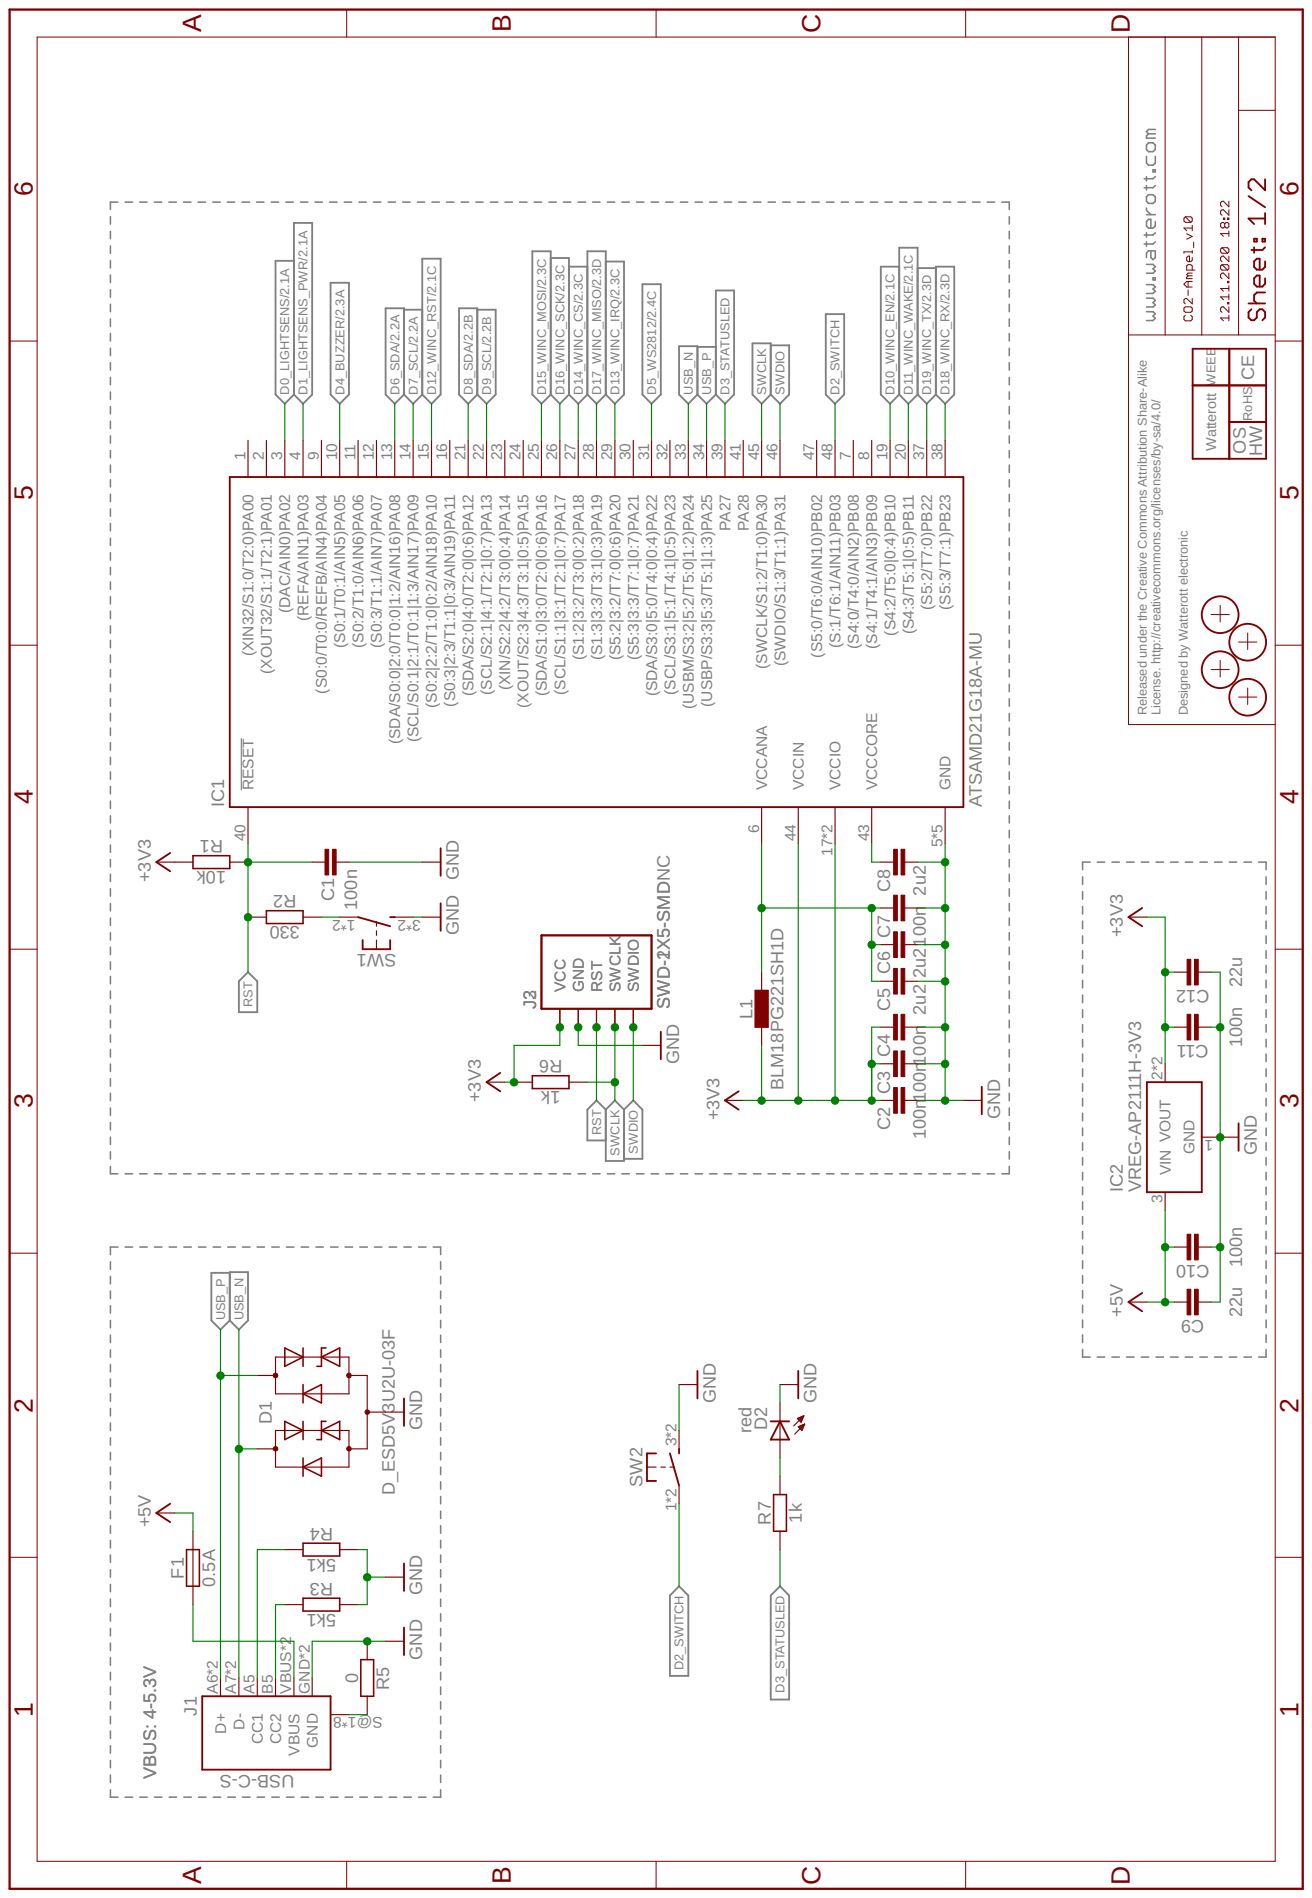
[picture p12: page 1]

VBUS: 4-5.3V VBUS: 4-5.3V ATSAMD21G18A-MU +3V3 GND +3V3 GND 0 0.5A +5VD_ESD5V3U2U-03F GND VREG-AP2111H-3V3 +5V GND 100n 100n red 1k 2u2 100n 2u2 100n GND GND k01 033 +3V3 k1 100n 100n 100n 22u 22u GND +3V3 GND BLM18PG221SH1D 2u2 GND 1k5 1k5 GND Released under the Creative Commons Attribution Share-Alike License. http:/ creativecommons.org/licenses/by-sa/4.0/ Designed by Watterott electronic OS HW RESET 40 GND 5*5 VCCANA 6 (XIN32/S1:0/T2:0)PA00 1 (XOUT32/S1:1/T2:1)PA01 2 (DAC/AIN0)PA02 3 (REFA/AIN1)PA03 4 (S0:0/T0:0/REFB/AIN4)PA04 9 (S0:1/T0:1/AIN5)PA05 10 (S0:2/T1:0/AIN6)PA06 11 (S0:3/T1:1/AIN7)PA07 12 (SDA/S0:0|2:0/T0:0|1:2/AIN16)PA08 13 (SCL/S0:1|2:1/T0:1|1:3/AIN17)PA09 14 (S0:2|2:2/T1:0|0:2/AIN18)PA10 15 (S0:3|2:3/T1:1|0:3/AIN19)PA11 16 (SDA/S2:0|4:0/T2:0|0:6)PA12 21 (SCL/S2:1|4:1/T2:1|0:7)PA13 22 (XIN/S2:2|4:2/T3:0|0:4)PA14 23 (XOUT/S2:3|4:3/T3:1|0:5)PA15 24 (SDA/S1:0|3:0/T2:0|0:6)PA16 25 (SCL/S1:1|3:1/T2:1|0:7)PA17 26 (S1:2|3:2/T3:0|0:2)PA18 27 (S1:3|3:3/T3:1|0:3)PA19 28 (S5:2|3:2/T7:0|0:6)PA20 29 (S5:3|3:3/T7:1|0:7)PA21 30 (SDA/S3:0|5:0/T4:0|0:4)PA22 31 (SCL/S3:1|5:1/T4:1|0:5)PA23 32 (USBM/S3:2|5:2/T5:0|1:2)PA24 33 (USBP/S3:3|5:3/T5:1|1:3)PA25 34 PA27 39 PA28 41 (SWCLK/S1:2/T1:0)PA30 45 (SWDIO/S1:3/T1:1)PA31 46 (S5:0/T6:0/AIN10)PB02 47 (S:1/T6:1/AIN11)PB03 48 (S4:0/T4:0/AIN2)PB08 7 (S4:1/T4:1/AIN3)PB09 8 (S4:2/T5:0|0:4)PB10 19 (S4:3/T5:1|0:5)PB11 20 (S5:2/T7:0)PB22 37 (S5:3/T7:1)PB23 38 VCCIO 17*2 VCCIN 44 VCCCORE 43 IC1 2* 1 2* 3 1 WS SWCLK SWDIO VCC GND RST J2SWD-2X5-SMD R5 F1 D1 GND VIN 3 V1 OUT 2*2 IC2 01 C 11 C D2 R7 C8 C7 C5 C1 1 R 2 R 6 R C4 C3 C2 9 C 21 C 1*2 3*2 SW2 L1 C6 CE RoHSWEEE Watterott D+ A6*2 D- A7*2 VBUS VBUS*2 GND GND*2 8* 1 @S CC1 A5 CC2 B5 J1 S- C- BSU 3 R4 R SWCLK SWDIO VCC GND RST J3SWD-1X5-SMDNC D15_WINC_MOSI/2.3C D16_WINC_SCK/2.3C D6_SDA/2.2A D7_SCL/2.2A SWCLK SWCLK SWDIO SWDIO RST RST D17_WINC_MISO/2.3D USB_N USB_N USB_P USB_P D11_WINC_WAKE/2.1C D14_WINC_CS/2.3C D18_WINC_RX/2.3D D19_WINC_TX/2.3D D13_WINC_IRQ/2.3C D8_SDA/2.2B D9_SCL/2.2B D5_WS2812/2.4C D10_WINC_EN/2.1C D4_BUZZER/2.3A D2_SWITCH D2_SWITCH D12_WINC_RST/2.1C D1_LIGHTSENS_PWR/2.1A D0_LIGHTSENS/2.1A D3_STATUSLED D3_STATUSLED ABCD 1 2 3 4 5 6 ABCD 1 2 3 4 5 6

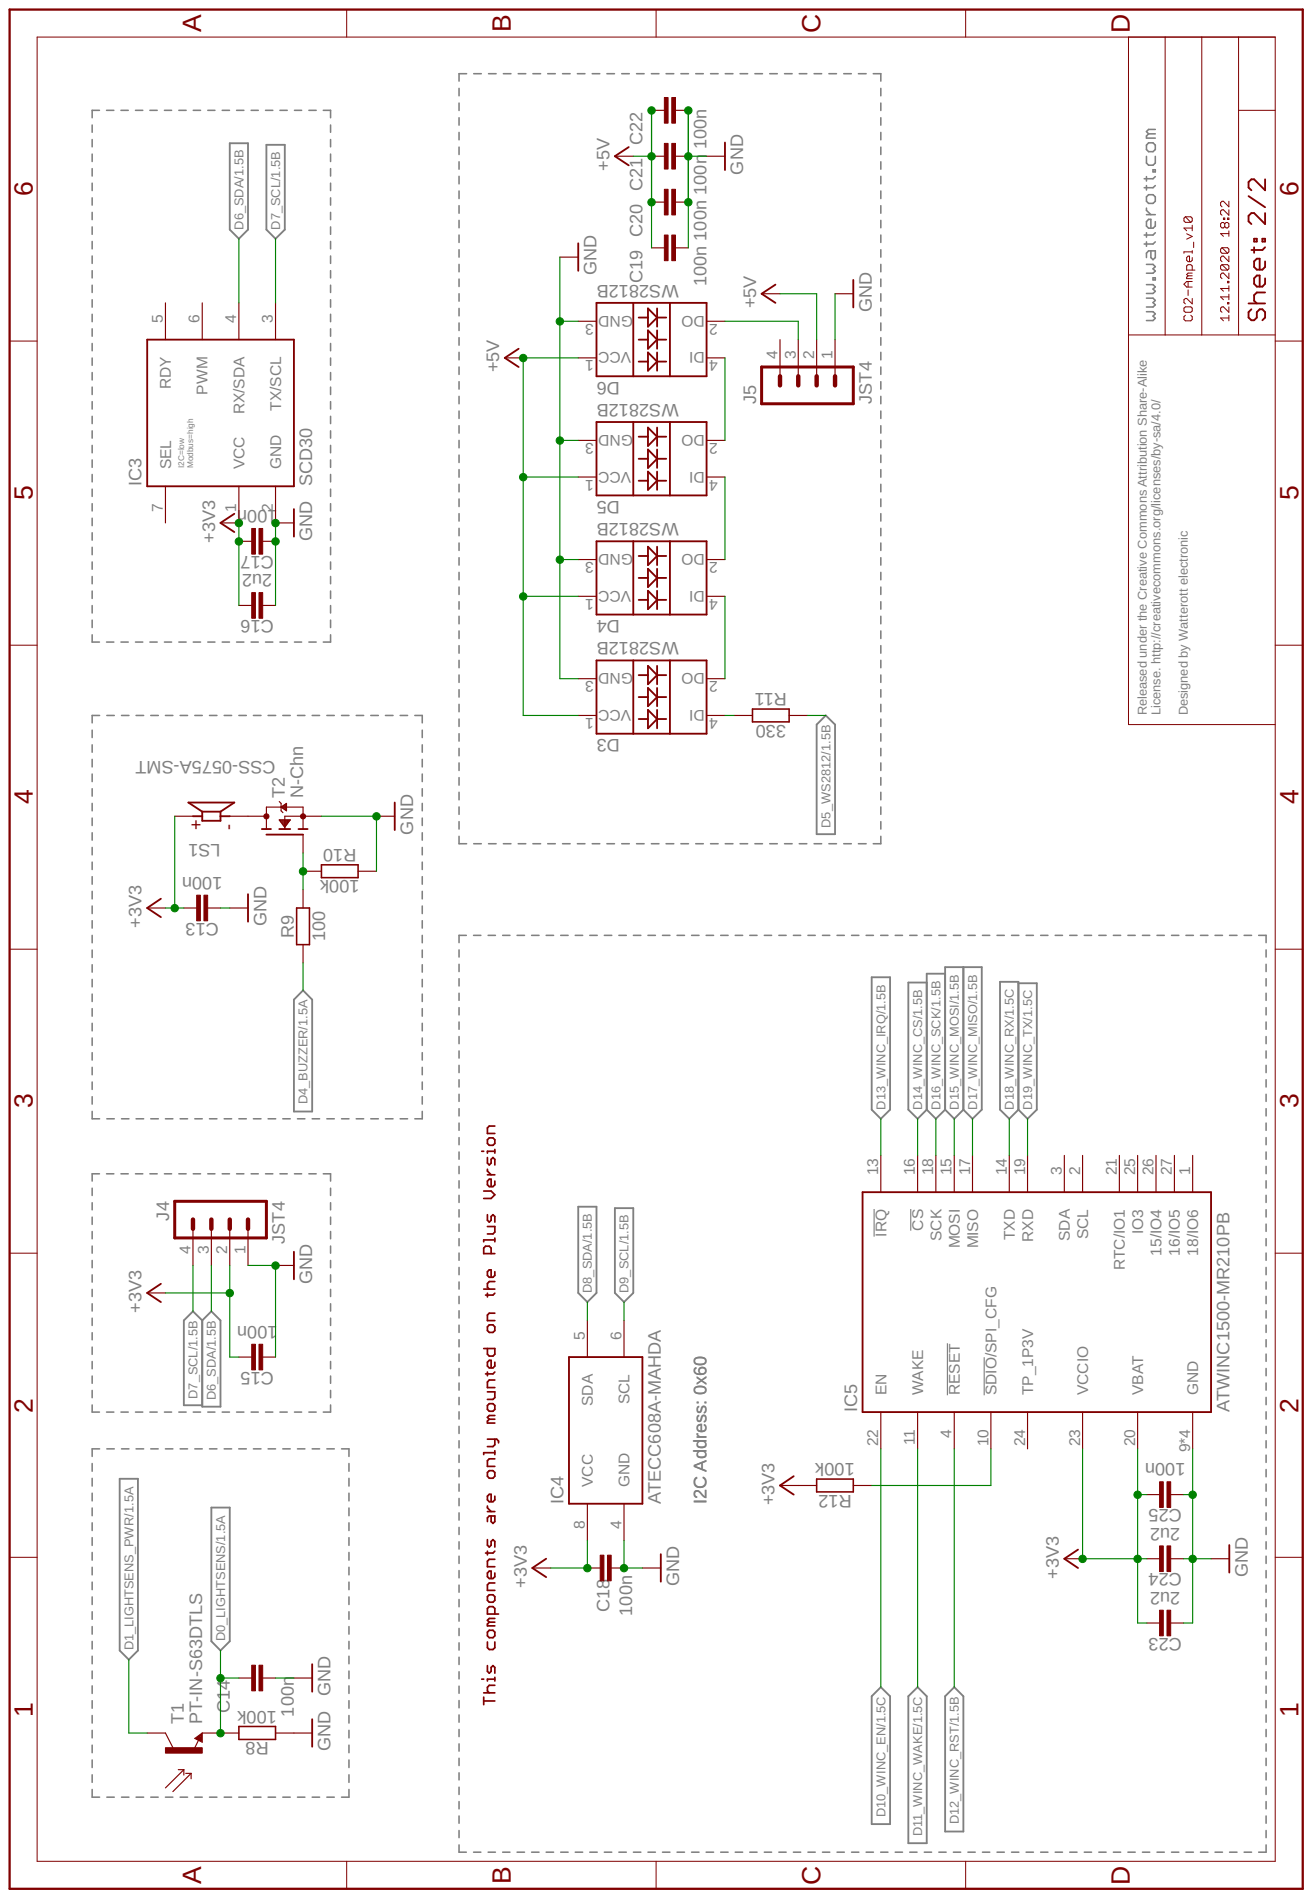
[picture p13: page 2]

I2C Address: 0x60 I2C Address: 0x60 n001 +3V3 GND +3V3k001 ATWINC1500-MR210PB 2u2 B2182S W B2182S W B2182S W B2182S W SCD30 GND 033 +3V3 GND 100n 100n 100n +5V GND k001 GND JST4 GND +3V3 N-Chn +3V3 GND k001 100 T MS- A5750- SSC +3V3 100nGND JST4 GND +5V 100nGND 2u2 n001 2u2 +5V 100n n001 n001 GND PT-IN-S63DTLS Released under the Creative Commons Attribution Share-Alike License. http:/ creativecommons.org/licenses/by-sa/4.0/ Designed by Watterott electronic 52 C 21 R 16/IO5 27 SCL 2 SDA 3 RESET 4 GND 9*4 SDIO/SPI_CFG 10 WAKE 11 IRQ 13 TXD 14 MOSI 15 CS 16 MISO 17 SCK 18 RXD 19 VBAT 20 RTC/IO1 21 EN 22 VCCIO 23 18/IO6 1 IO3 25 15/IO4 26 TP_1P3V 24 IC5 42 C 42 13 CCV DNG ODI D 6 D 42 13 CCV DNG ODI D 5 D 42 13 CCV DNG ODI D 4 D 42 13 CCV DNG ODI D 3 D TX/SCL 3 VCC 1 RX/SDA 4 GND 2 PWM 6 RDY 5 SEL 7 I2C=low Modbus=high IC3 11 R C20 C21 C22 8 R 4321 J4 T2 01 R R9 1SL C18 SCL 6 SDA 5 VCC 8 GND 4 IC4 ATECC608A-MAHDA 4321 J5 C14 32 C 71 C 61 C C19 51 C 31 C T1 D15_WINC_MOSI/1.5B D16_WINC_SCK/1.5B D17_WINC_MISO/1.5B D18_WINC_RX/1.5C D10_WINC_EN/1.5C D11_WINC_WAKE/1.5C D5_WS2812/1.5B D12_WINC_RST/1.5B D6_SDA/1.5B D6_SDA/1.5B D7_SCL/1.5B D7_SCL/1.5B D0_LIGHTSENS/1.5A D4_BUZZER/1.5A D8_SDA/1.5B D9_SCL/1.5B D14_WINC_CS/1.5B D19_WINC_TX/1.5C D1_LIGHTSENS_PWR/1.5A D13_WINC_IRQ/1.5B ABCD 1 2 3 4 5 6 ABCD 1 2 3 4 5 6 +-

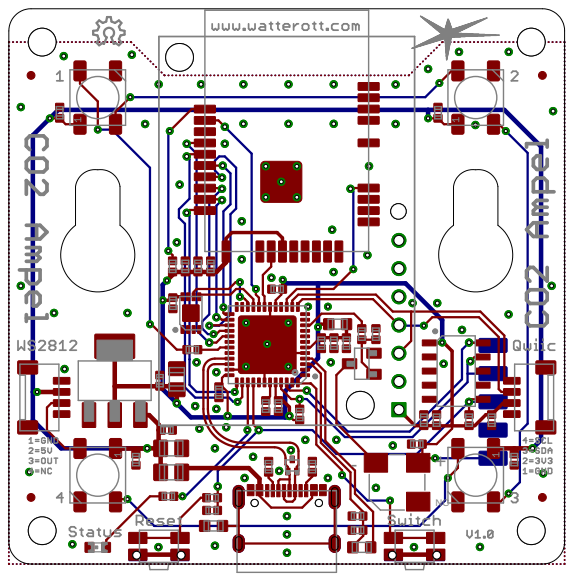
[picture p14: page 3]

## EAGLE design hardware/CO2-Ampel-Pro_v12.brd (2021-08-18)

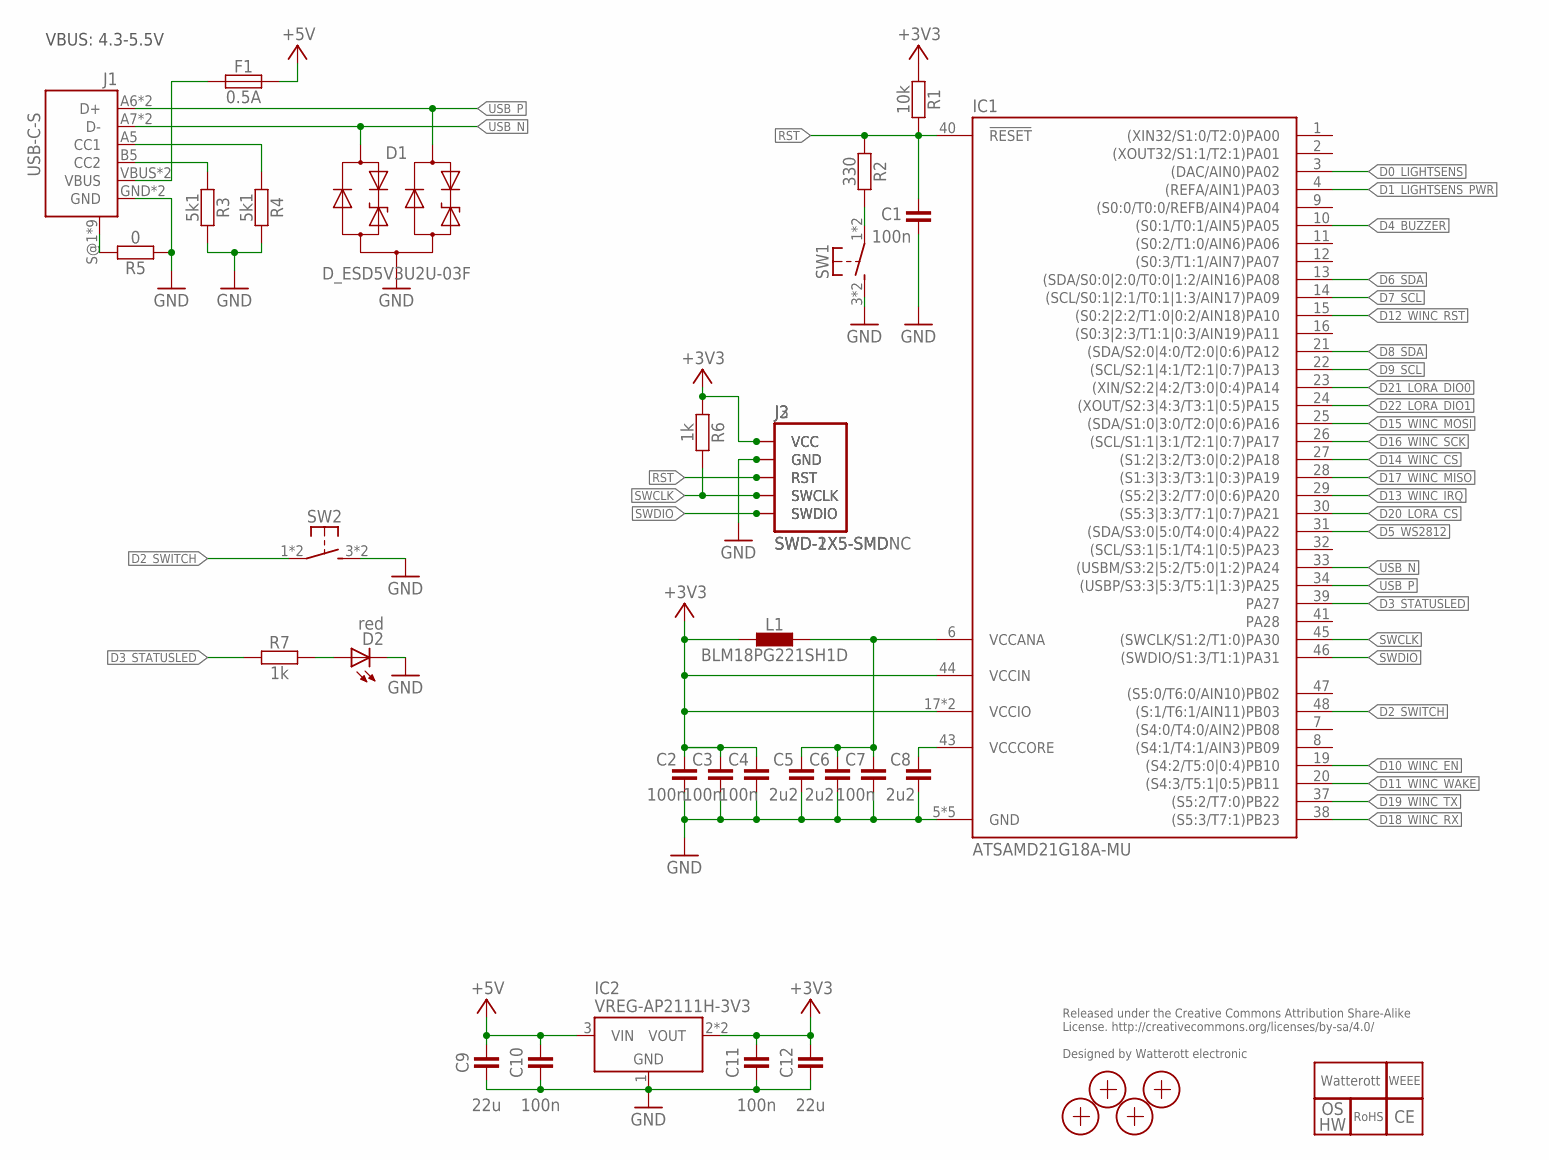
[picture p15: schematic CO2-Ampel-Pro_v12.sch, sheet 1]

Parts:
C1, C2, C3, C4, C7, C10, C11: 100n; C0402
C5, C6, C8: 2u2; C0402
C9, C12: 22u; C0805
D1: D_ESD5V3U2U-03F; SOT723
D2: red; C0603
F1: 0.5A; C0805
IC1: ATSAMD21G18A-MU; QFN48-PAD
IC2: VREG-AP2111H-3V3; SOT223
J1: USB-C-S
J2: SWD-2X5-SMD; SWD-2X5_SMD
J3: SWD-1X5-SMDNC; SWD-1X5_SMDNC
L1: BLM18PG221SH1D; C0603
LOGO1: LOGO_SPARK-4; SPARK_4MM
LOGO2: LOGO_WEEE-4; WEEE_4MM
LOGO3: OSHW_LOGOX0070; OSHW_3MM
LOGO4: LOGO_ROHS-4; ROHS_4MM
LOGO5: LOGO_CE-4; CE_4MM
R1: 10k; C0402
R2: 330; C0402
R3, R4: 5k1; C0402
R5: 0; C0603
R6, R7: 1k; C0402
SW1: PTS645SK50SMTR92-Red; PTS840P
SW2: PTS645SH50SMTR92-Grey; PTS840P
X1, X2, X3, X4: PASSER-07; PASSER_07MM

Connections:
+3V3: C2.2, C3.2, C4.2, C11.2, C12.2, IC1.17 (VCCIO), IC1.36 (VCCIO), IC1.44 (VCCIN), IC2.2 (VOUT), IC2.4 (VOUT), J2.VCC, J3.1-VCC (VCC), L1.1, R1.1, R6.1; also elsewhere on the board
+5V: C9.2, C10.2, F1.2, IC2.3 (VIN); also elsewhere on the board
CC1: J1.A5 (CC1), R4.1
CC2: J1.B5 (CC2), R3.1
D0_LIGHTSENS: IC1.3 ((DAC/AIN0)PA02); also elsewhere on the board
D1_LIGHTSENS_PWR: IC1.4 ((REFA/AIN1)PA03); also elsewhere on the board
D2_SWITCH: IC1.48 ((S:1/T6:1/AIN11)PB03), SW2.1, SW2.2 (P1)
D3_STATUSLED: IC1.39 (PA27), R7.1
D4_BUZZER: IC1.10 ((S0:1/T0:1/AIN5)PA05); also elsewhere on the board
D5_WS2812: IC1.31 ((SDA/S3:0|5:0/T4:0|0:4)PA22); also elsewhere on the board
D6_SDA: IC1.13 ((SDA/S0:0|2:0/T0:0|1:2/AIN16)PA08); also elsewhere on the board
D7_SCL: IC1.14 ((SCL/S0:1|2:1/T0:1|1:3/AIN17)PA09); also elsewhere on the board
D8_SDA: IC1.21 ((SDA/S2:0|4:0/T2:0|0:6)PA12); also elsewhere on the board
D9_SCL: IC1.22 ((SCL/S2:1|4:1/T2:1|0:7)PA13); also elsewhere on the board
D10_WINC_EN: IC1.19 ((S4:2/T5:0|0:4)PB10); also elsewhere on the board
D11_WINC_WAKE: IC1.20 ((S4:3/T5:1|0:5)PB11); also elsewhere on the board
D12_WINC_RST: IC1.15 ((S0:2|2:2/T1:0|0:2/AIN18)PA10); also elsewhere on the board
D13_WINC_IRQ: IC1.29 ((S5:2|3:2/T7:0|0:6)PA20); also elsewhere on the board
D14_WINC_CS: IC1.27 ((S1:2|3:2/T3:0|0:2)PA18); also elsewhere on the board
D15_WINC_MOSI: IC1.25 ((SDA/S1:0|3:0/T2:0|0:6)PA16); also elsewhere on the board
D16_WINC_SCK: IC1.26 ((SCL/S1:1|3:1/T2:1|0:7)PA17); also elsewhere on the board
D17_WINC_MISO: IC1.28 ((S1:3|3:3/T3:1|0:3)PA19); also elsewhere on the board
D18_WINC_RX: IC1.38 ((S5:3/T7:1)PB23); also elsewhere on the board
D19_WINC_TX: IC1.37 ((S5:2/T7:0)PB22); also elsewhere on the board
D20_LORA_CS: IC1.30 ((S5:3|3:3/T7:1|0:7)PA21); also elsewhere on the board
D21_LORA_DIO0: IC1.23 ((XIN/S2:2|4:2/T3:0|0:4)PA14); also elsewhere on the board
D22_LORA_DIO1: IC1.24 ((XOUT/S2:3|4:3/T3:1|0:5)PA15); also elsewhere on the board
GND: C1.1, C2.1, C3.1, C4.1, C5.1, C6.1, C7.1, C8.1, C9.1, C10.1, C11.1, C12.1, D1.3 (A), D2.C, IC1.5 (GND), IC1.18 (GND), IC1.35 (GND), IC1.42 (GND), IC1.TP (GND), IC2.1 (GND), J1.GND, J1.GND2 (GND), J2.GND@1 (GND), J2.GND@2 (GND), J2.GND@3 (GND), J3.2-GND (GND), R3.2, R4.2, R5.1, SW1.3 (S1), SW1.4 (S1), SW2.3 (S1), SW2.4 (S1); also elsewhere on the board
unnamed: D2.A, R7.2
unnamed: R2.2, SW1.1, SW1.2 (P1)
RST: C1.2, IC1.40 (!RESET), J2.RST, J3.3-RST (RST), R1.2, R2.1
SHLD: J1.S@1 (SHIELD), J1.S@2 (SHIELD), J1.S@3 (SHIELD), J1.S@4 (SHIELD), J1.S@5 (SHIELD), J1.S@6 (SHIELD), J1.S@7 (SHIELD), J1.S@8 (SHIELD), J1.S@9 (SHIELD), R5.2
SWCLK: IC1.45 ((SWCLK/S1:2/T1:0)PA30), J2.SWCLK, J3.4-SWDCLK (SWCLK), R6.2
SWDIO: IC1.46 ((SWDIO/S1:3/T1:1)PA31), J2.SWDIO, J3.5-SWDIO (SWDIO)
USB_N: D1.1 (C1), IC1.33 ((USBM/S3:2|5:2/T5:0|1:2)PA24), J1.A7 (D-), J1.B7 (D-)
USB_P: D1.2 (C2), IC1.34 ((USBP/S3:3|5:3/T5:1|1:3)PA25), J1.A6 (D+), J1.B6 (D+)
VBUS: F1.1, J1.VBUS, J1.VBUS2 (VBUS)
VCCANA: C5.2, C6.2, C7.2, IC1.6 (VCCANA), L1.2
VCCCORE: C8.2, IC1.43 (VCCCORE)

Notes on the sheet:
Released under the Creative Commons Attribution Share-Alike License. http://creativecommons.org/licenses/by-sa/4.0/ Designed by Watterott electronic
VBUS: 4.3-5.5V

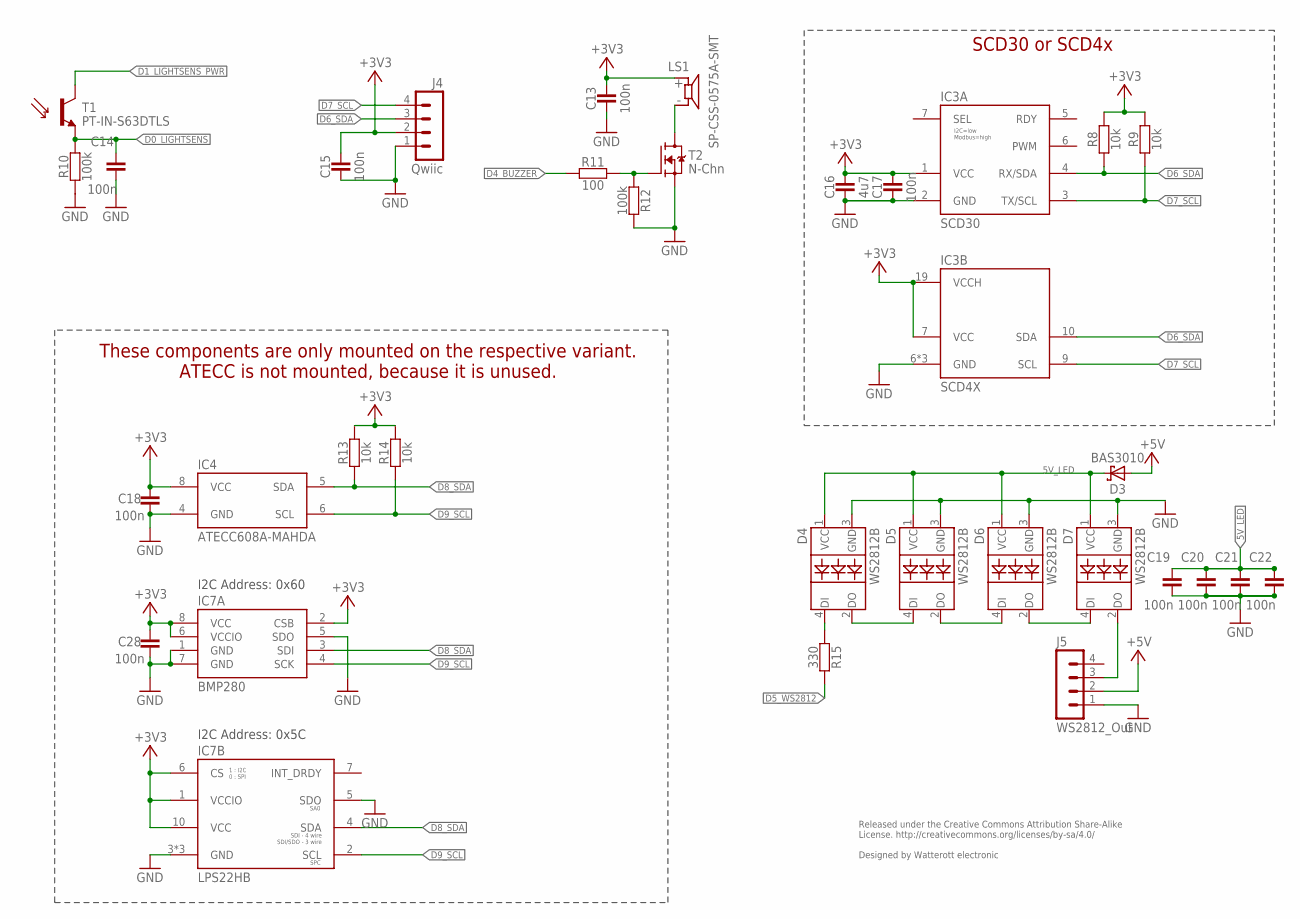
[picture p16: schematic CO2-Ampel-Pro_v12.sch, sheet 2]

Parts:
C13, C14, C15, C17, C18, C19, C20, C21, C22, C28: 100n; C0402
C16: 4u7; C0402
D3: BAS3010; SOD323
D4, D5, D6, D7: WS2812B
IC3A: SCD30
IC3B: SCD4X
IC4: ATECC608A-MAHDA; UDFN8
IC7A: BMP280; LGA8
IC7B: LPS22HB
J4: Qwiic; JST_SM04B-SRSS-TB
J5: WS2812_Out; JST_SM04B-SRSS-TB
LS1: SP-CSS-0575A-SMT; CUI_CSS-0575A-SMT
R8, R9, R13, R14: 10k; C0402
R10, R12: 100k; C0402
R11: 100; C0402
R15: 330; C0402
T1: PT-IN-S63DTLS; C0603T
T2: N-Chn; SOT23

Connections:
5V_LED: C19.2, C20.2, C21.2, C22.2, D3.C, D4.1 (VCC), D5.1 (VCC), D6.1 (VCC), D7.1 (VCC)
+3V3: C13.2, C15.2, C16.2, C17.2, C18.2, C28.2, IC3A.1 (VCC), IC3B.7 (VCC), IC3B.19 (VCCH), IC4.8 (VCC), IC7A.2 (CSB), IC7A.6 (VCCIO), IC7A.8 (VCC), IC7B.1 (VCCIO), IC7B.6 (CS), IC7B.10 (VCC), J4.2, LS1.+, R8.2, R9.2, R13.2, R14.2; also elsewhere on the board
+5V: D3.A, J5.2; also elsewhere on the board
D0_LIGHTSENS: C14.2, R10.2, T1.E; also elsewhere on the board
D1_LIGHTSENS_PWR: T1.C; also elsewhere on the board
D4_BUZZER: R11.1; also elsewhere on the board
D5_WS2812: R15.2; also elsewhere on the board
D6_SDA: IC3A.4 (RX/SDA), IC3B.10 (SDA), J4.3, R8.1; also elsewhere on the board
D7_SCL: IC3A.3 (TX/SCL), IC3B.9 (SCL), J4.4, R9.1; also elsewhere on the board
D8_SDA: IC4.5 (SDA), IC7A.3 (SDI), IC7B.4 (SDA), R13.1; also elsewhere on the board
D9_SCL: IC4.6 (SCL), IC7A.4 (SCK), IC7B.2 (SCL), R14.1; also elsewhere on the board
GND: C13.1, C14.1, C15.1, C16.1, C17.1, C18.1, C19.1, C20.1, C21.1, C22.1, C28.1, D4.3 (GND), D5.3 (GND), D6.3 (GND), D7.3 (GND), IC3A.2 (GND), IC3B.6 (GND), IC3B.20 (GND), IC3B.21 (GND), IC4.4 (GND), IC7A.1 (GND), IC7A.5 (SDO), IC7A.7 (GND), IC7B.3 (GND), IC7B.5 (SDO), IC7B.8 (GND), IC7B.9 (GND), J4.1, J5.1, R10.1, R12.2, T2.2 (S); also elsewhere on the board
unnamed: LS1.- (N), T2.3 (D)
unnamed: R11.2, R12.1, T2.1 (G)
W1IN: D4.4 (DI), R15.1
W1OUT: D4.2 (DO), D5.4 (DI)
W2OUT: D5.2 (DO), D6.4 (DI)
W3OUT: D6.2 (DO), D7.4 (DI)
W4OUT: D7.2 (DO), J5.3

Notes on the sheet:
I2C Address: 0x60
Released under the Creative Commons Attribution Share-Alike License. http://creativecommons.org/licenses/by-sa/4.0/ Designed by Watterott electronic
I2C Address: 0x5C
These components are only mounted on the respective variant. ATECC is not mounted, because it is unused.
SCD30 or SCD4x

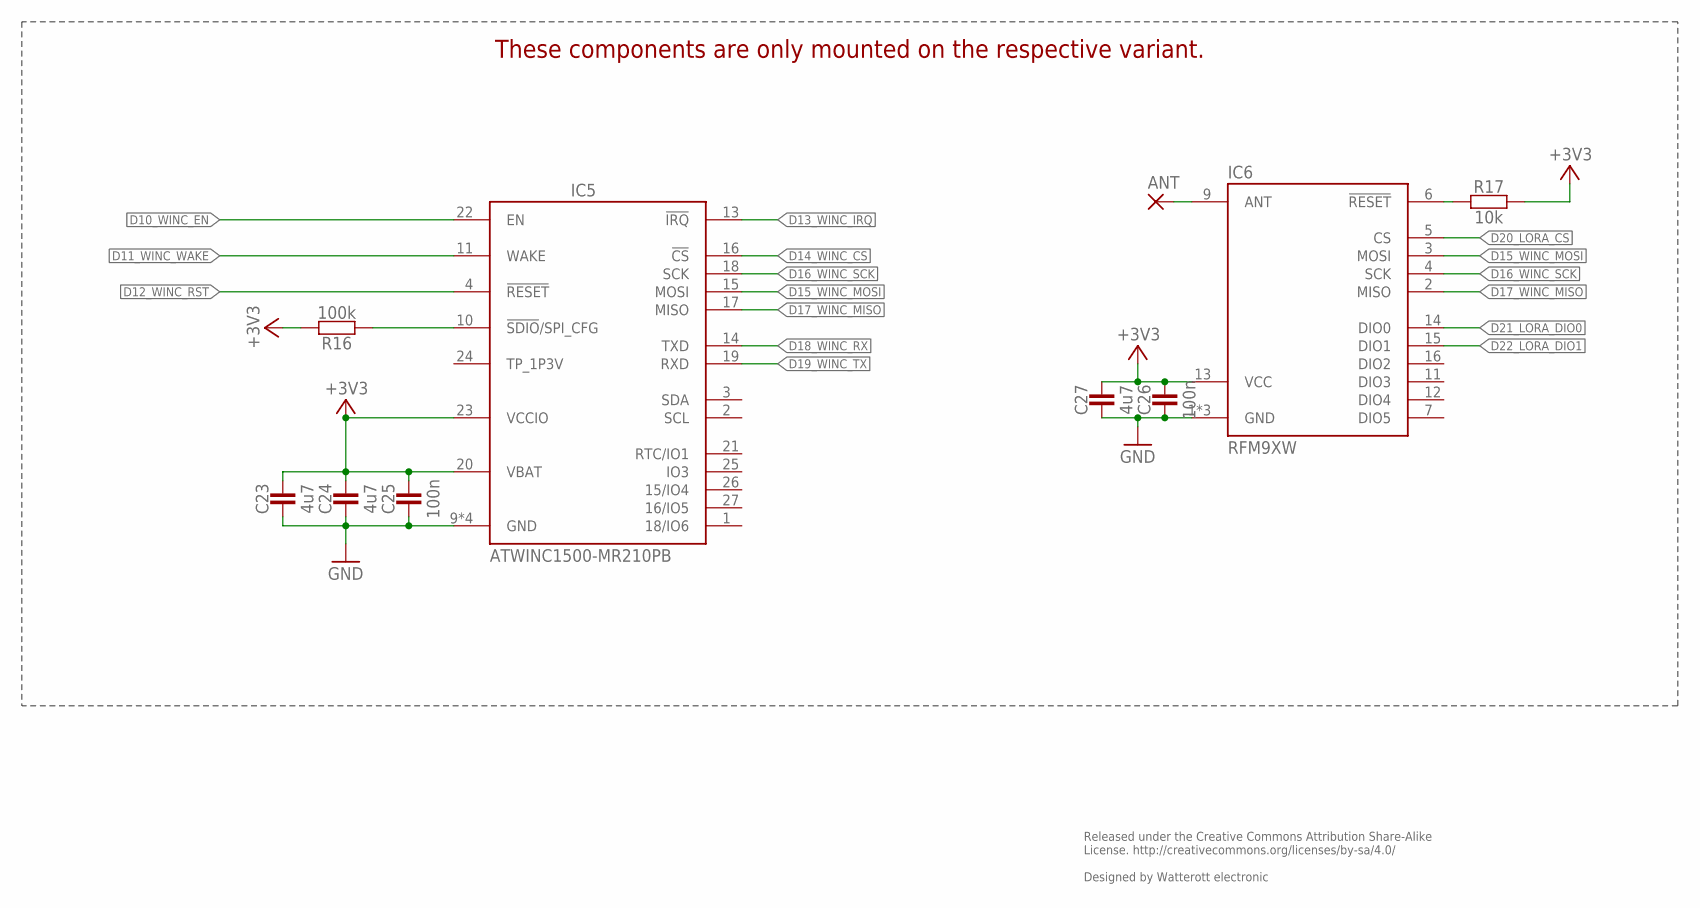
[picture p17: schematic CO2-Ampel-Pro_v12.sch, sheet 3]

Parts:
ANT: 1,6/0,9
C23, C24, C27: 4u7; C0402
C25, C26: 100n; C0402
IC5: ATWINC1500-MR210PB; ATWINC1500-MX210
IC6: RFM9XW; RFM9X
R16: 100k; C0402
R17: 10k; C0402

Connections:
+3V3: C23.2, C24.2, C25.2, C26.2, C27.2, IC5.20 (VBAT), IC5.23 (VCCIO), IC6.13 (VCC), R16.2, R17.2; also elsewhere on the board
CFG: IC5.10 (!SDIO!/SPI_CFG), R16.1
D10_WINC_EN: IC5.22 (EN); also elsewhere on the board
D11_WINC_WAKE: IC5.11 (WAKE); also elsewhere on the board
D12_WINC_RST: IC5.4 (!RESET); also elsewhere on the board
D13_WINC_IRQ: IC5.13 (!IRQ); also elsewhere on the board
D14_WINC_CS: IC5.16 (!CS); also elsewhere on the board
D15_WINC_MOSI: IC5.15 (MOSI), IC6.3 (MOSI); also elsewhere on the board
D16_WINC_SCK: IC5.18 (SCK), IC6.4 (SCK); also elsewhere on the board
D17_WINC_MISO: IC5.17 (MISO), IC6.2 (MISO); also elsewhere on the board
D18_WINC_RX: IC5.14 (TXD); also elsewhere on the board
D19_WINC_TX: IC5.19 (RXD); also elsewhere on the board
D20_LORA_CS: IC6.5 (CS); also elsewhere on the board
D21_LORA_DIO0: IC6.14 (DIO0); also elsewhere on the board
D22_LORA_DIO1: IC6.15 (DIO1); also elsewhere on the board
GND: C23.1, C24.1, C25.1, C26.1, C27.1, IC5.9 (GND), IC5.12 (GND), IC5.28 (GND), IC5.GND, IC6.1 (GND), IC6.8 (GND), IC6.10 (GND); also elsewhere on the board
unnamed: ANT.1, IC6.9 (ANT)
unnamed: IC6.6 (!RESET), R17.1

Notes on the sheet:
Released under the Creative Commons Attribution Share-Alike License. http://creativecommons.org/licenses/by-sa/4.0/ Designed by Watterott electronic
These components are only mounted on the respective variant.

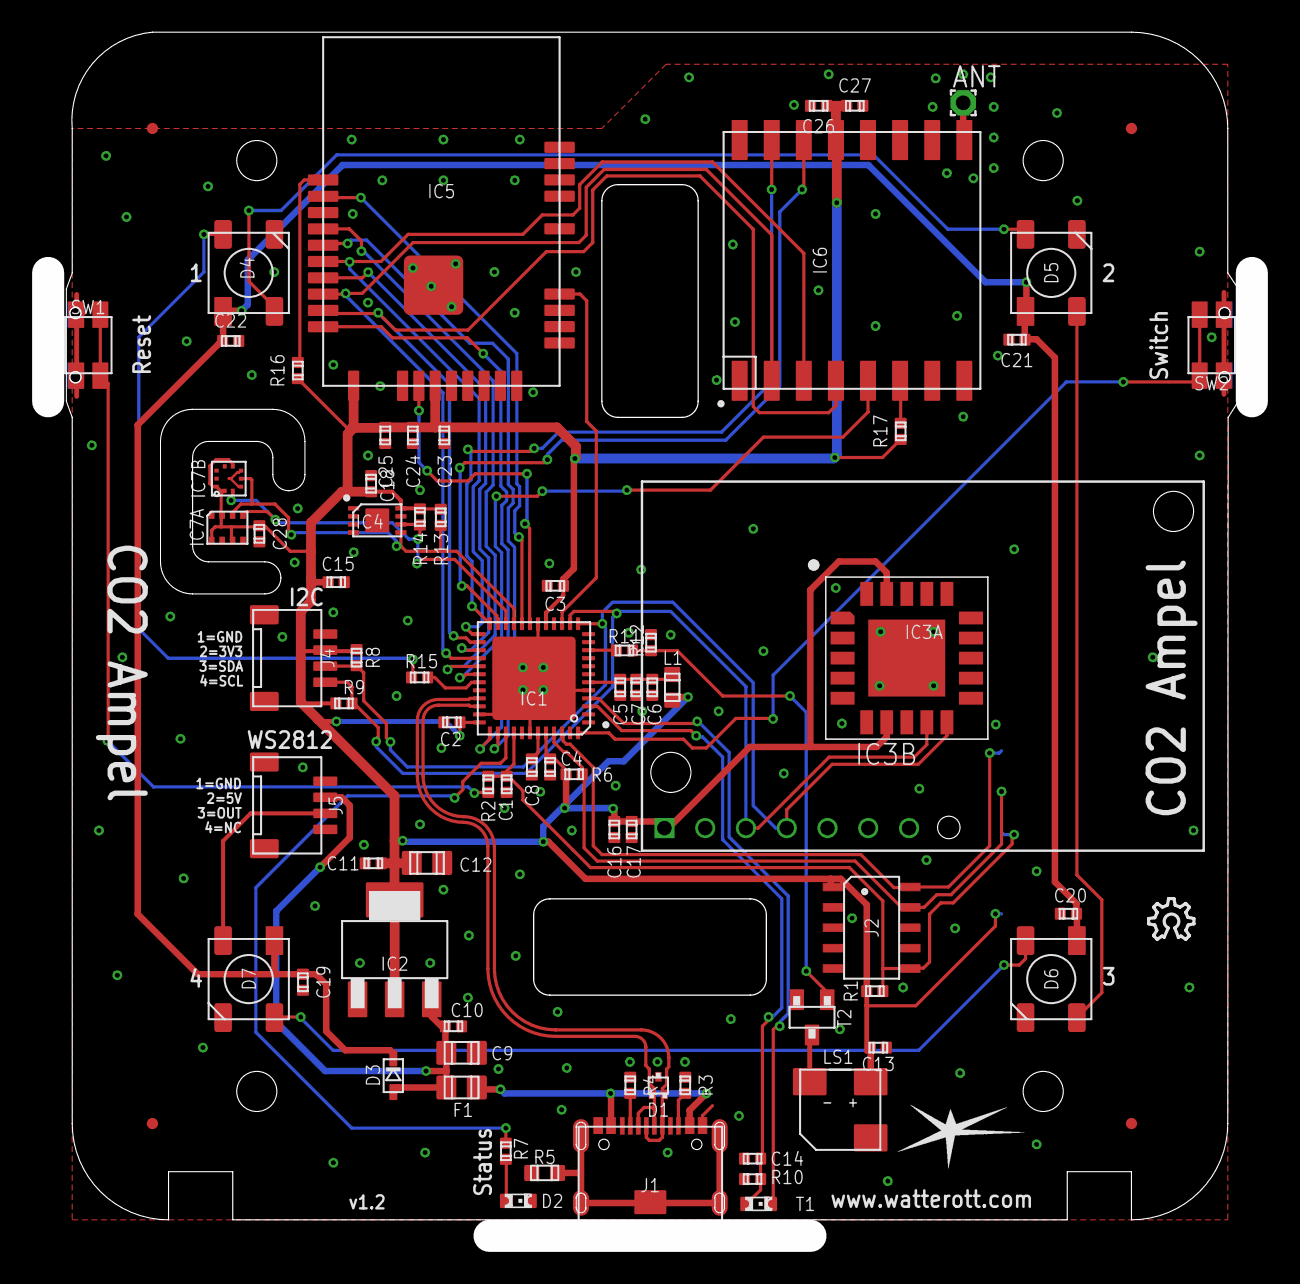
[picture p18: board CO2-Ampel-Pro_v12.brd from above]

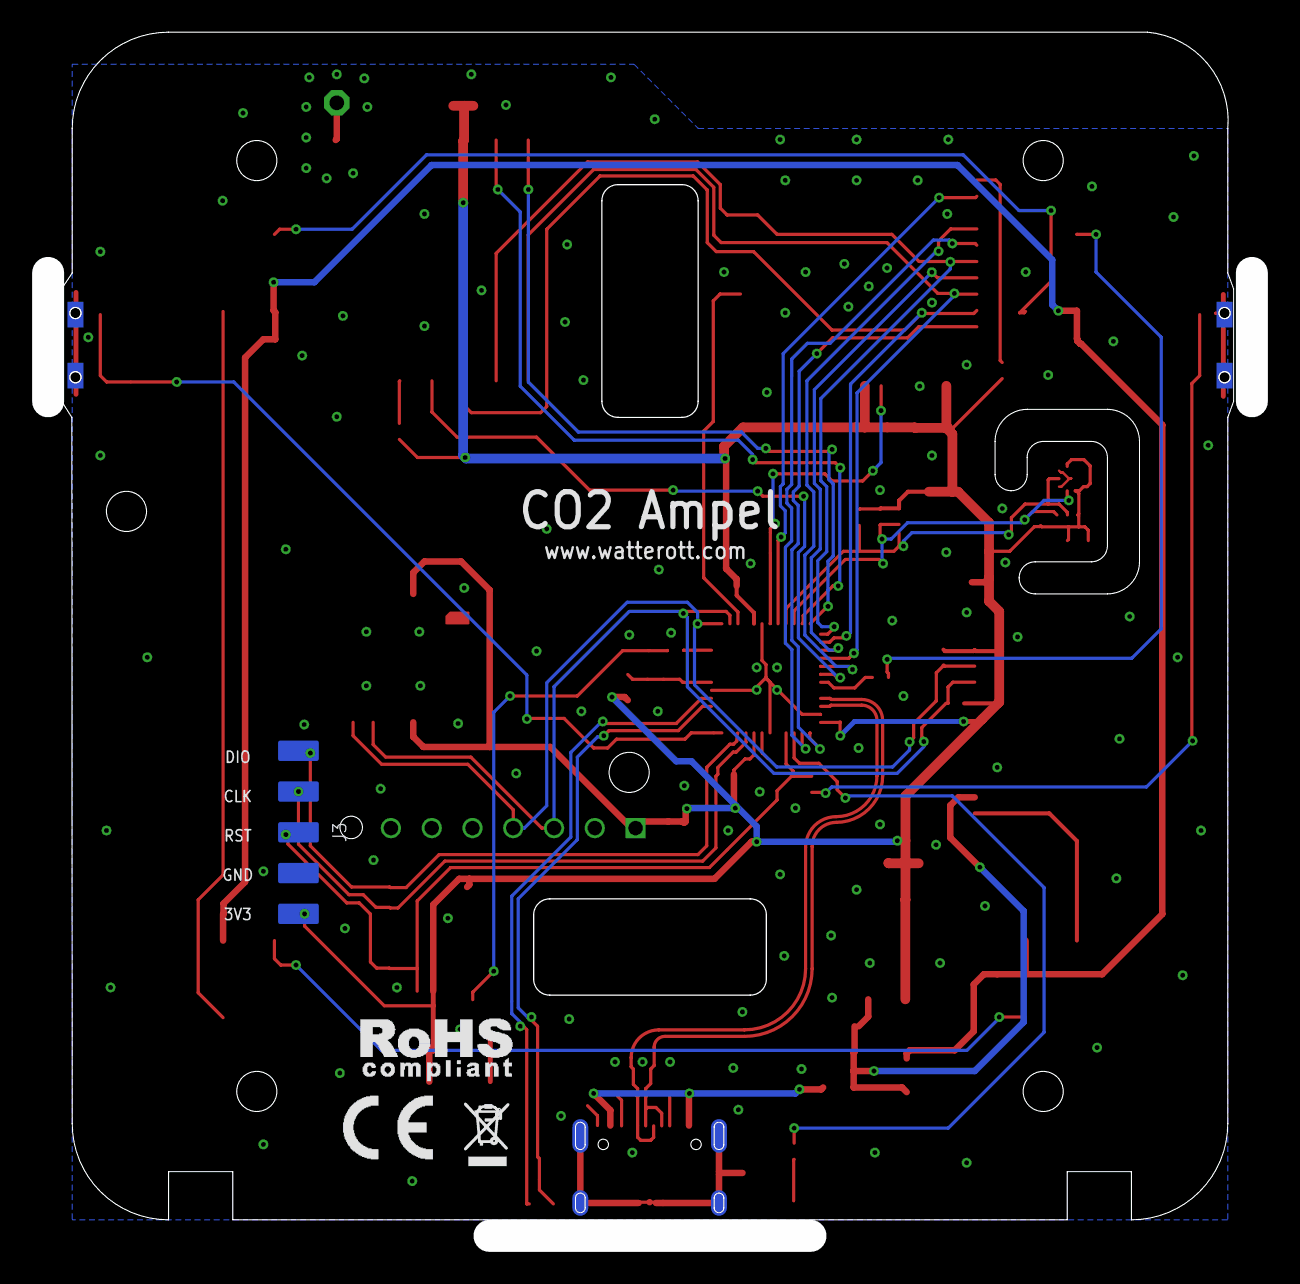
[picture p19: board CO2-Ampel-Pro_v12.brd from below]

Board: 2 copper layers, 75.0 x 75.0 mm, 83 parts (4 on the bottom side), 50 nets.

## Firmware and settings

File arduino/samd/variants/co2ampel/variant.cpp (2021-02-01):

/*
  Copyright (c) 2014-2015 Arduino LLC.  All right reserved.

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
  You should have received a copy of the GNU Lesser General Public
  License along with this library; if not, write to the Free Software
  Foundation, Inc., 51 Franklin St, Fifth Floor, Boston, MA  02110-1301  USA
*/

#include "variant.h"
#include "Arduino.h"

const PinDescription g_APinDescription[] = {

/*
 +------------+------------------+--------+-----------------+--------+-----------------------+---------+---------+--------+--------+----------+----------+
 | Pin number | Board pin        |  PIN   | Notes           | Peri.A |     Peripheral B      | Perip.C | Perip.D | Peri.E | Peri.F | Periph.G | Periph.H |
 |            |                  |        |                 |   EIC  | ADC |  AC | PTC | DAC | SERCOMx | SERCOMx |  TCCx  |  TCCx  |    COM   | AC/GLCK  |
 |            |                  |        |                 |(EXTINT)|(AIN)|(AIN)|     |     | (x/PAD) | (x/PAD) | (x/WO) | (x/WO) |          |          |
 +------------+------------------+--------+-----------------+--------+-----+-----+-----+-----+---------+---------+--------+--------+----------+----------+
 | 00         | Light Sensor     |  PA02  |                 |   02   | *00 |     | Y00 | OUT |         |         |        |        |          |          |
 | 01         | Light Sensor Pwr |  PA03  |                 |   03   |  01 |     | Y01 |     |         |         |        |        |          |          |
 | 02         | Switch           |  PB03  |                 |  *03   | *11 |     | Y09 |     |         |   5/01  |        |        |          |          |
 | 03         | LED red          |  PA27  |                 |   15   |     |     |     |     |         |         |        |        |          | GCLK_IO0 |
 | 04         | Buzzer           |  PA05  |                 |   05   | *05 |  01 | Y03 |     |         |   0/01  |*TCC0/1 |        |          |          |
 | 05         | WS2812 LEDs      |  PA22  |                 |  *06   |     |     | X10 |     |   3/00  |   5/00  |* TC4/0 | TCC0/4 |          | GCLK_IO6 |
 +------------+------------------+--------+-----------------+--------------------+-----+-----+---------+---------+--------+--------+----------+----------+
 | 06         | SDA SCD30        |  PA08  |                 |   NMI  | *16 |     | X00 |     |  *0/00  |   2/00  | TCC0/0 | TCC1/2 | I2S/SD1  |          |
 | 07         | SCL SCD30        |  PA09  |                 |   09   | *17 |     | X01 |     |  *0/01  |   2/01  | TCC0/1 | TCC1/3 | I2S/MCK0 |          |
 +------------+------------------+--------+-----------------+--------------------+-----+-----+---------+---------+--------+--------+----------+----------+
 | 08         | SDA ATECC        |  PA12  |                 |   12   |     |     |     |     |  *2/00  |   4/00  | TCC2/0 | TCC0/6 |          | AC/CMP0  |
 | 09         | SCL ATECC        |  PA13  |                 |   13   |     |     |     |     |  *2/01  |   4/01  | TCC2/1 | TCC0/7 |          | AC/CMP1  |
  +------------+------------------+--------+-----------------+--------------------+-----+-----+---------+---------+--------+--------+----------+----------+
 | 10         | WINC En          |  PB10  |                 |  *10   |     |     |     |     |         |   4/02  |* TC5/0 | TCC0/4 | I2S/MCK1 | GCLK_IO4 |
 | 11         | WINC Wake        |  PB11  |                 |  *11   |     |     |     |     |         |   4/03  |* TC5/1 | TCC0/5 | I2S/SCK1 | GCLK_IO5 |
 | 12         | WINC Rst         |  PA10  |                 |   10   | *18 |     | X02 |     |   0/02  |   2/02  |*TCC1/0 | TCC0/2 | I2S/SCK0 | GCLK_IO4 |
 | 13         | WINC Irq         |  PA20  |                 |  *04   |     |     | X08 |     |   5/02  |   3/02  |        |*TCC0/6 | I2S/SCK0 | GCLK_IO4 |
 | 14         | WINC CS          |  PA18  |                 |   02   |     |     | X06 |     |   1/02  |   3/02  |  TC3/0 | TCC0/2 |          | AC/CMP0  |
 | 15         | WINC MOSI        |  PA16  |                 |  *00   |     |     | X04 |     |  *1/00  |   3/00  |*TCC2/0 | TCC0/6 |          | GCLK_IO2 |
 | 16         | WINC SCK         |  PA17  |                 |  *01   |     |     | X05 |     |  *1/01  |   3/01  | TCC2/1 | TCC0/7 |          | GCLK_IO3 |
 | 17         | WINC MISO        |  PA19  |                 |   03   |     |     | X07 |     |  *1/03  |   3/03  |* TC3/1 | TCC0/3 | I2S/SD0  | AC/CMP1  |
 | 18         | WINC RX          |  PB23  |                 |   07   |     |     |     |     |         |  *5/03  |        |        |          | GCLK_IO1 |
 | 19         | WINC TX          |  PB22  |                 |   06   |     |     |     |     |         |  *5/02  |        |        |          | GCLK_IO0 |
 | 20         | RFM9X CS         |  PA21  |                 |  *05   |     |     | X09 |     |   5/03  |   3/03  |        |*TCC0/7 | I2S/FS0  | GCLK_IO5 |
 | 21         | RFM9X DIO0       |  PA14  |                 |   14   |     |     |     |     |   2/02  |   4/02  |  TC3/0 | TCC0/4 |          | GCLK_IO0 |
 | 22         | RFM9X DIO1       |  PA15  |                 |   15   |     |     |     |     |  *2/03  |   4/03  |  TC3/1 | TCC0/5 |          | GCLK_IO1 |
 +------------+------------------+--------+-----------------+--------+-----+-----+-----+-----+---------+---------+--------+--------+----------+----------+
 */
  { PORTA,  2, PIO_ANALOG,  (PIN_ATTR_DIGITAL|PIN_ATTR_ANALOG /*DAC*/        ), ADC_Channel0,   NOT_ON_PWM, NOT_ON_TIMER, EXTERNAL_INT_2    }, // Light
  { PORTA,  3, PIO_ANALOG,  (PIN_ATTR_DIGITAL                                ), ADC_Channel1,   NOT_ON_PWM, NOT_ON_TIMER, EXTERNAL_INT_3    }, // Light Pwr
  { PORTB,  3, PIO_DIGITAL, (PIN_ATTR_DIGITAL                                ), No_ADC_Channel, NOT_ON_PWM, NOT_ON_TIMER, EXTERNAL_INT_NONE }, // SW
  { PORTA, 27, PIO_DIGITAL, (PIN_ATTR_DIGITAL                                ), No_ADC_Channel, NOT_ON_PWM, NOT_ON_TIMER, EXTERNAL_INT_NONE }, // LED
  { PORTA,  5, PIO_DIGITAL, (PIN_ATTR_DIGITAL|PIN_ATTR_PWM|PIN_ATTR_TIMER    ), No_ADC_Channel, PWM0_CH1,   TCC0_CH1,     EXTERNAL_INT_NONE }, // Buzzer
  { PORTA, 22, PIO_DIGITAL, (PIN_ATTR_DIGITAL                                ), No_ADC_Channel, NOT_ON_PWM, NOT_ON_TIMER, EXTERNAL_INT_NONE }, // WS2812
                                                                                                                                               // PINOUT=1
  { PORTA,  8, PIO_SERCOM,  (PIN_ATTR_DIGITAL                                ), No_ADC_Channel, NOT_ON_PWM, NOT_ON_TIMER, EXTERNAL_INT_NONE }, // SDA: SERCOM0/PAD[0]
  { PORTA,  9, PIO_SERCOM,  (PIN_ATTR_DIGITAL                                ), No_ADC_Channel, NOT_ON_PWM, NOT_ON_TIMER, EXTERNAL_INT_NONE }, // SCL: SERCOM0/PAD[1]
                                                                                                                                               // PINOUT=1
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

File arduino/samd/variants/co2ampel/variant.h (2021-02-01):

/*
  Copyright (c) 2014-2015 Arduino LLC.  All right reserved.

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
  You should have received a copy of the GNU Lesser General Public
  License along with this library; if not, write to the Free Software
  Foundation, Inc., 51 Franklin St, Fifth Floor, Boston, MA  02110-1301  USA
*/

#pragma once

// The definitions here needs a SAMD core >=1.6.10
#define ARDUINO_SAMD_VARIANT_COMPLIANCE 10610

#include <WVariant.h>

// General definitions
// -------------------

// Frequency of the board main oscillator
#define VARIANT_MAINOSC (32768ul)
#define CRYSTALLESS //no ext. crystal

// Master clock frequency
#define VARIANT_MCK     (48000000ul)

// Pins
// ----

// Number of pins defined in PinDescription array
#define PINS_COUNT           (27u) // 27
#define NUM_DIGITAL_PINS     (23u) // 23
#define NUM_ANALOG_INPUTS    (2u)  // 2
#define NUM_ANALOG_OUTPUTS   (0u)  // 0
#define analogInputToDigitalPin(p)  ((p < 2u) ? (p) : -1)

// Low-level pin register query macros
// -----------------------------------
#define digitalPinToPort(P)      (&(PORT->Group[g_APinDescription[P].ulPort]))
#define digitalPinToBitMask(P)   (1 << g_APinDescription[P].ulPin)
//#define analogInPinToBit(P)    ()
#define portOutputRegister(port) (&(port->OUT.reg))
#define portInputRegister(port)  (&(port->IN.reg))
#define portModeRegister(port)   (&(port->DIR.reg))
#define digitalPinHasPWM(P)      (g_APinDescription[P].ulPWMChannel != NOT_ON_PWM || g_APinDescription[P].ulTCChannel != NOT_ON_TIMER)

/*
 * digitalPinToTimer(..) is AVR-specific and is not defined for SAMD
 * architecture. If you need to check if a pin supports PWM you must
 * use digitalPinHasPWM(..).
 *
 * https://github.com/arduino/Arduino/issues/1833
 */
// #define digitalPinToTimer(P)

// CO2-Ampel pins
// --------------
#define PIN_LSENSOR     (0u)
#define PIN_LSENSOR_PWR (1u)
#define PIN_SWITCH      (2u)
#define PIN_BUZZER      (4u)
#define PIN_WS2812      (5u)


// LEDs
// ----
#define PIN_LED      (3u) // PA27 (red)
#define LED_BUILTIN  PIN_LED

// Analog pins
// -----------
#define PIN_A0   (0u)
#define PIN_A1   (1u)
#define PIN_DAC0 (0u)

static const uint8_t A0   = PIN_A0;
static const uint8_t A1   = PIN_A1;
static const uint8_t DAC0 = PIN_DAC0;
#define ADC_RESOLUTION 12

// SPI Interfaces
// --------------
#define SPI_INTERFACES_COUNT 1

// SPI
#define PIN_SPI_SS    (14u)
#define PIN_SPI_MOSI  (15u)
#define PIN_SPI_SCK   (16u)
#define PIN_SPI_MISO  (17u)
#define PERIPH_SPI    sercom1 // sercom1 or sercom3
#define PAD_SPI_TX    SPI_PAD_0_SCK_1
#define PAD_SPI_RX    SERCOM_RX_PAD_3
static const uint8_t SS   = PIN_SPI_SS;   // SPI Slave SS not used. Set here only for reference.
static const uint8_t MOSI = PIN_SPI_MOSI;
static const uint8_t MISO = PIN_SPI_MISO;
static const uint8_t SCK  = PIN_SPI_SCK;

// Wire Interfaces
// ---------------
#define WIRE_INTERFACES_COUNT 2

// Wire
#define PIN_WIRE_SDA        (6u)
#define PIN_WIRE_SCL        (7u)
#define PERIPH_WIRE         sercom0 // sercom0 or sercom2
#define WIRE_IT_HANDLER     SERCOM0_Handler
static const uint8_t SDA = PIN_WIRE_SDA;
static const uint8_t SCL = PIN_WIRE_SCL;

#define PIN_WIRE1_SDA       (8u) // ATECC
#define PIN_WIRE1_SCL       (9u) // ATECC
#define PERIPH_WIRE1        sercom2 // sercom2 or sercom4
#define WIRE1_IT_HANDLER    SERCOM2_Handler
static const uint8_t SDA1 = PIN_WIRE1_SDA;
static const uint8_t SCL1 = PIN_WIRE1_SCL;

// USB
// ---
#define PIN_USB_DM          (23u)
#define PIN_USB_DP          (24u)
//#define PIN_USB_HOST_ENABLE (-1u)

// Needed for WINC1501B (WiFi101) library
// --------------------------------------
#define WINC1501_RESET_PIN   (12u) // reset pin
#define WINC1501_WAKE_PIN    (11u) // wake pin
#define WINC1501_CHIP_EN_PIN (10u) // enable pin
#define WINC1501_INTN_PIN    (13u) // int pin
#define WINC1501_SPI         SPI
#define WINC1501_SPI_CS_PIN  (14u) // cs pin

// Needed for SD library
// ---------------------
//#define SDCARD_SS_PIN       (-1u)

// Serial ports
// ------------
#ifdef __cplusplus
#include "SERCOM.h"
#include "Uart.h"

// Instances of SERCOM
extern SERCOM sercom0;
extern SERCOM sercom1;
extern SERCOM sercom2;
extern SERCOM sercom3;
extern SERCOM sercom4;
extern SERCOM sercom5;

// SERCOM3 oder SERCOM5 Serial1 UART RXTX1
extern Uart Serial1;
#define PIN_SERIAL1_RX (19u)
#define PIN_SERIAL1_TX (18u)
#define PAD_SERIAL1_TX (UART_TX_PAD_0)
#define PAD_SERIAL1_RX (SERCOM_RX_PAD_1)

#endif // __cplusplus

#ifdef __cplusplus
extern "C" {
#endif
unsigned int PINCOUNT_fn();
#ifdef __cplusplus
}
#endif

// These serial port names are intended to allow libraries and architecture-neutral
// sketches to automatically default to the correct port name for a particular type
// of use.  For example, a GPS module would normally connect to SERIAL_PORT_HARDWARE_OPEN,
// the first hardware serial port whose RX/TX pins are not dedicated to another use.
//
// SERIAL_PORT_MONITOR        Port which normally prints to the Arduino Serial Monitor
//
// SERIAL_PORT_USBVIRTUAL     Port which is USB virtual serial
//
// SERIAL_PORT_LINUXBRIDGE    Port which connects to a Linux system via Bridge library
//
// SERIAL_PORT_HARDWARE       Hardware serial port, physical RX & TX pins.
//
// SERIAL_PORT_HARDWARE_OPEN  Hardware serial ports which are open for use.  Their RX & TX
//                            pins are NOT connected to anything by default.
#define SERIAL_PORT_USBVIRTUAL      SerialUSB
#define SERIAL_PORT_MONITOR         SerialUSB
#define SERIAL_PORT_HARDWARE        Serial1
#define SERIAL_PORT_HARDWARE_OPEN   Serial1

// Alias Serial to SerialUSB
#define Serial                      SerialUSB

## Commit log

2020-10-31 added readme and schematics
2020-10-31 Arduino BSP
    [co2ampel.cfg]
2020-11-12 added layout and schematics
    [CO2-Ampel_v10.brd, CO2-Ampel_v10.sch]
2020-12-02 updated schematics
    [CO2-Ampel_v10.brd, CO2-Ampel_v10.sch]
2020-12-02 added rev 1.1
    [CO2-Ampel_v11.brd, CO2-Ampel_v11.sch]
2021-01-29 enable pullups on I2C
2021-05-27 SCD30/SCD4x air pressure compensation
2021-06-08 Temperature offset for pro variant
2021-08-18 added CO2-Ampel Pro v1.2
    [CO2-Ampel-Pro_v12.brd, CO2-Ampel-Pro_v12.sch]
2021-08-18 added enclosure

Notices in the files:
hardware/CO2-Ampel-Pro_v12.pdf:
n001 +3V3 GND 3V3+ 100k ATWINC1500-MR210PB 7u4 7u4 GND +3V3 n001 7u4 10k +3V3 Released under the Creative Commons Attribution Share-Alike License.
